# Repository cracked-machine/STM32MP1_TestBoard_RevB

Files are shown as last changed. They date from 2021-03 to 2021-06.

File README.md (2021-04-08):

### STM32MP1 Embedded Linux breakout board RevB

A development board for the STM32MP1 Application Microprocessor with *all MPU pins routed through to 2.54mm headers.* No exotic proprietary connectors needed!

#### Power Supply

The power supply requirements for microprocessors are always complicated. I decided to use a discrete power supply scheme using a single LDO for the main 3.3V rail, a buck regulator for the DDR 1.35V rail and a load switch to detect the USB 1.8V rail. The latter comes from an internal regulator ands powers the VDD3V3_USBFS and VDD3V3_USBHS. This needs to be enabled only after the 1.8V rail comes up, so this needs to be enabled using a MOSFET. However, you need to pick a transistor that will fully switch on for 1.8V Vgs. After having some issues I played it safe with a load switch: the [SIP3250](https://www.mouser.co.uk/datasheet/2/427/sip32508-1763863.pdf), which turns on as low as 1.2V...according to the datasheet

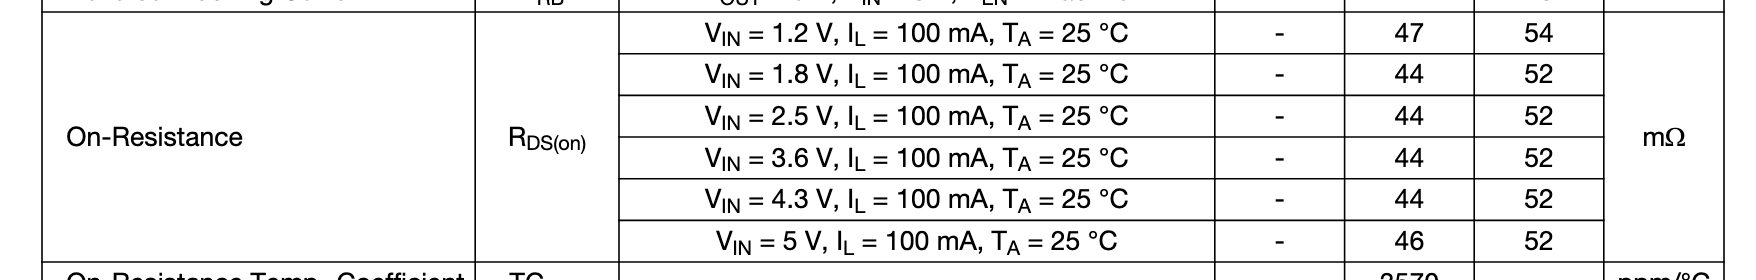
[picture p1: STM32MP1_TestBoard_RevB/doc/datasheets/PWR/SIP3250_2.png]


The characteristics seem to back this up until you get to the Fig.10. Perhaps not quite as good as 1.2Vgs but even at 1.5Vgs, this is more than good enough for these requirements.
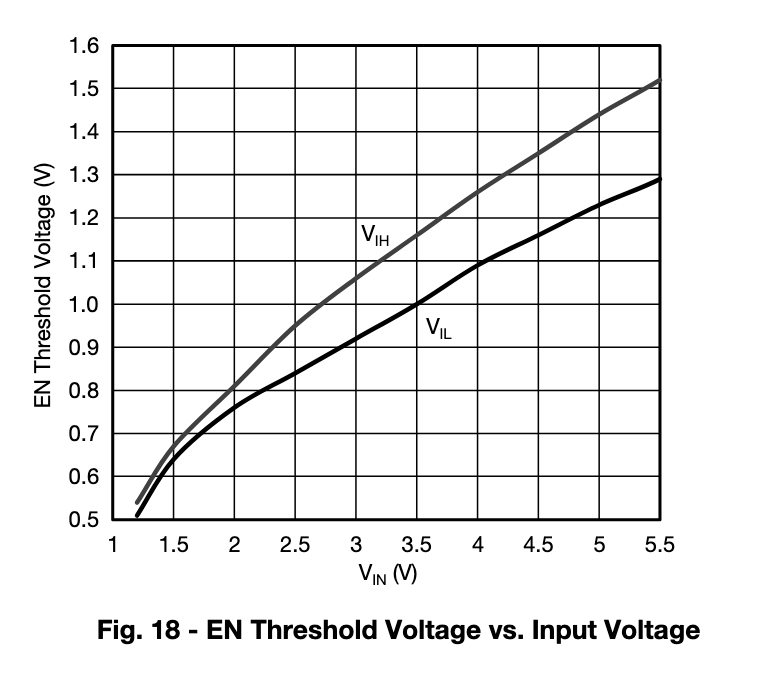
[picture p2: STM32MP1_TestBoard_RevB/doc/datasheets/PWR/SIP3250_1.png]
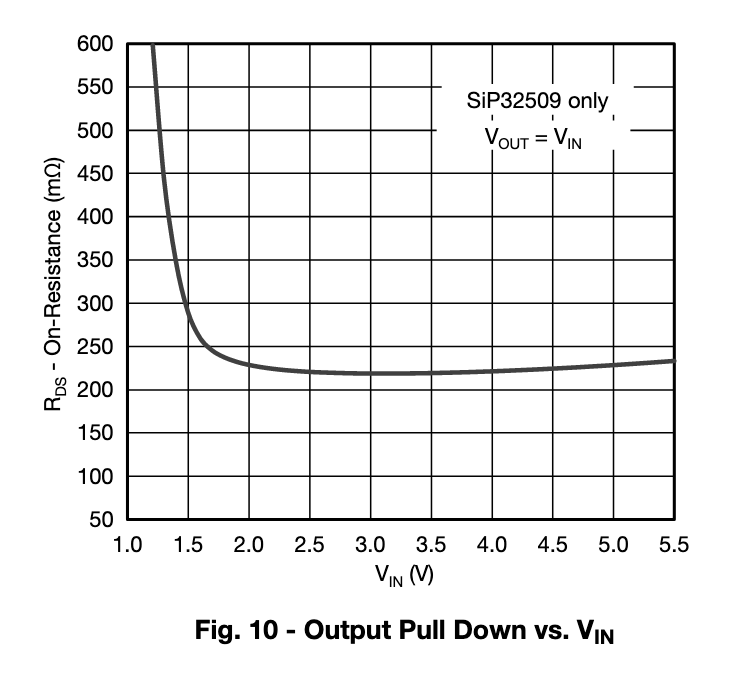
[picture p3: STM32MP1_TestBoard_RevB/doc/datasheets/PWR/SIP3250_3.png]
|||
|:---:|:---:|

Whether this is too much hassle when you can use a single PMIC is debatable. The sheer number of passive components needed to support a PMIC is eye-watering. 

The table below lists the power supply scheme on this board:

|Power Supply Rail|MPU Pin Name|MPU Pin #|Comment|
|:---:|:---|:---|:---:|
|3.3v|VDD<br>VBAT<br>VDD_PLL <br>VDD_PLL2<br>VDD_ANA<br>VDD_DSI<br>PDR_ON_CORE<br>PDR_ON|K6<br>H3<br>J5<br>G13<br>L3<br>A12<br>N1<br>N2|Linear regulator ([SE8233X2](https://datasheet.lcsc.com/szlcsc/1912111437_Seaward-Elec-SE8233X2_C437587.pdf))|
|3.3v|VDDA<br>VREF+|M4<br>N3|via inductor L3<br>If JP4 is connected (default)|
|3.3v|VDD3V3_USBFS<br>VDD3V3_USBHS|W12<br>W15|via NMOS ([DMG2302U](https://datasheet.octopart.com/DMG2302U-7-Diodes-Inc.-datasheet-103571615.pdf)) when 1.85v rail is detected from MPU
|1.35v|VDD<br>VDDQ<br>VDDCORE<br>VDDQ_DDR|B2<br>A1<br>E7<br>E15|Buck regulator [TPS54202](http://www.ti.com/lit/ds/symlink/tps54202.pdf)
|1.85v|VDDA1V8_REG|V11|Internal regulator, externally connect to VDDA1V8_DSI (B12)
|1.2v|VDD1V2_DSI_REG|B16|Internal regulator, externally connected to VDD1V2_DSI_PHY (A16)
|1.1v|VDDA1V1_REG|W11|Interal regulator, internally connected.|

*Note*: 3.3v rail is also connected to:
- SWD debug interface
- SDIO connectors (microSD)
- pull-ups for the BOOT pins
- external power output on the pin headers (pin #26 on J1, J2, J3, J4)

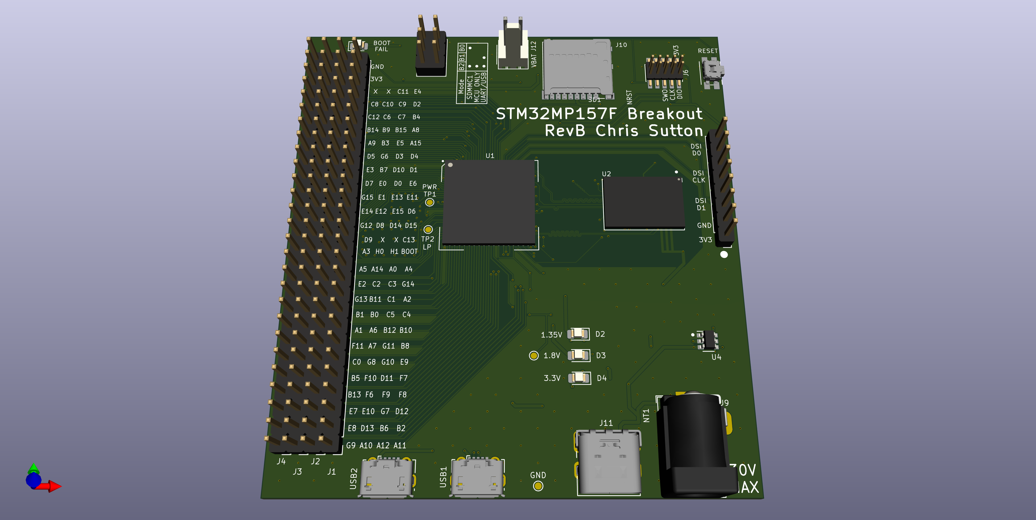
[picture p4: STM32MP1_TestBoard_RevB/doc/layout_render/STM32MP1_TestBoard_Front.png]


[Bill of materials](STM32MP1_TestBoard_RevB/doc/bom/STM32MP1_TestBoard_RevB.csv)

[DataSheets](STM32MP1_TestBoard_RevB/doc/datasheets)

### <U>Schematics:</U>

|Overview|Power Supply|
|:---:|:---:|
||

|STM32MP1 Power|STM32MP1 DDR|
|:---:|:---:|
|||

|STM32MP1 GPIO|STM32MP1 Debug|
|:---:|:---:|
|||

### <U>Testing the bare metal board</U>

Before we boot the board with a Linux image. It is helpful to check the MPU is alive and responding. We can use the SEGGER JLink to connect to the cores via the SWD connector (J6). 

#### Connect to the first A7 core (second core is not active by default):
BOOT pins  must be set to B0 and B2.
```
JLinkExe -device STM32MP15XX_A7_0_DUALFLASH -if SWD -speed 4000 -autoconnect 1
```

```
SEGGER J-Link Commander V6.98a (Compiled Mar  5 2021 17:04:44)
DLL version V6.98a, compiled Mar  5 2021 17:04:29

Connecting to J-Link via USB...O.K.
Firmware: J-Link V11 compiled Feb  4 2021 12:59:17
Hardware version: V11.00
S/N: 261002652
License(s): FlashBP, GDB
OEM: SEGGER-EDU
VTref=3.341V
Device "STM32MP15XX_A7_0_DUALFLASH" selected.

Connecting to target via SWD
ConfigTargetSettings() start
ConfigTargetSettings() end
InitTarget() start
InitTarget() end
Found SW-DP with ID 0x6BA02477
DPIDR: 0x6BA02477
AP map detection skipped. Manually configured AP map found.
AP[0]: AXI-AP (IDR: Not set)
AP[1]: APB-AP (IDR: Not set)
AP[2]: AHB-AP (IDR: Not set)
Using preconfigured AP[1] as APB-AP
AP[1]: APB-AP found
Found Cortex-A7 r0p5
6 code breakpoints, 4 data breakpoints
Debug architecture ARMv7.1
Data endian: little
Main ID register: 0x410FC075
I-Cache L1: 32 KB, 512 Sets, 32 Bytes/Line, 2-Way
D-Cache L1: 32 KB, 128 Sets, 64 Bytes/Line, 4-Way
Unified-Cache L2: 256 KB, 512 Sets, 64 Bytes/Line, 8-Way
System control register:
  Instruction endian: little
  Level-1 instruction cache enabled
  Level-1 data cache enabled
  MMU enabled
  Branch prediction enabled
Memory zones:
  Zone: Default Description: Default access mode
  Zone: APB-AP (AP1) Description: DMA like acc. in AP1 addr. space
  Zone: AHB-AP (AP2) Description: DMA like acc. in AP2 addr. space
Cortex-A7 identified.

```

#### Connect to the M4 core:
BOOT pins  must be set to B2 only.
```
JLinkExe -device STM32MP15XX_M4_DUALFLASH -if SWD -speed 4000 -autoconnect 1
```

```
SEGGER J-Link Commander V6.98a (Compiled Mar  5 2021 17:04:44)
DLL version V6.98a, compiled Mar  5 2021 17:04:29

Connecting to J-Link via USB...O.K.
Firmware: J-Link V11 compiled Feb  4 2021 12:59:17
Hardware version: V11.00
S/N: 261002652
License(s): FlashBP, GDB
OEM: SEGGER-EDU
VTref=3.342V
Device "STM32MP15XX_M4_DUALFLASH" selected.

Connecting to target via SWD
ConfigTargetSettings() start
ConfigTargetSettings() end
InitTarget() start
InitTarget() end
Found SW-DP with ID 0x6BA02477
DPIDR: 0x6BA02477
AP map detection skipped. Manually configured AP map found.
AP[0]: AXI-AP (IDR: Not set)
AP[1]: APB-AP (IDR: Not set)
AP[2]: AHB-AP (IDR: Not set)
AP[2]: Core found
AP[2]: AHB-AP ROM base: 0xE00FF000
CPUID register: 0x410FC241. Implementer code: 0x41 (ARM)
Found Cortex-M4 r0p1, Little endian.
FPUnit: 6 code (BP) slots and 2 literal slots
Detection of Coresight components via ROM table search disabled by user
Cortex-M4 identified.

```

Here is a photo successfully connecting to the A7 core on the assembled board using JLink (via SWD). It lives!

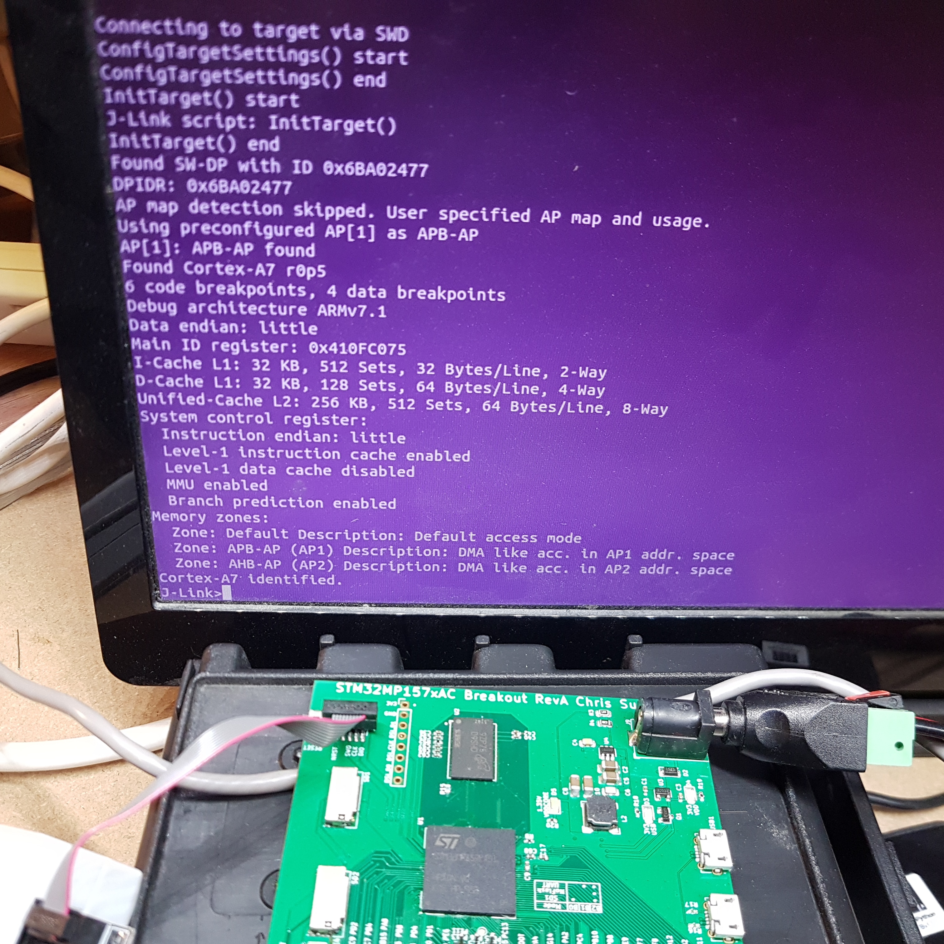
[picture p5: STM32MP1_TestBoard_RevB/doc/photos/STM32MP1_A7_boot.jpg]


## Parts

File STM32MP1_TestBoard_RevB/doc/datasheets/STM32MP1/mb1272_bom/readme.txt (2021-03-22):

******************************************************************************
* @file    readme.txt
* @author  MCD Application Team
* @version 1.0
* @date    17-January-2019 
* @brief   32MP157DISCOVERY BOM files package
******************************************************************************
* COPYRIGHT(c) 2017 STMicroelectronics
*
* The Open Platform License Agreement (“Agreement”) is a binding legal contract
* between you ("You") and STMicroelectronics International N.V. (“ST”), a
* company incorporated under the laws of the Netherlands acting for the purpose
* of this Agreement through its Swiss branch 39, Chemin du Champ des Filles,
* 1228 Plan-les-Ouates, Geneva, Switzerland.
*
* By using the enclosed reference designs, schematics, PC board layouts, and
* documentation, in hardcopy or CAD tool file format (collectively, the
* “Reference Material”), You are agreeing to be bound by the terms and
* conditions of this Agreement. Do not use the Reference Material until You
* have read and agreed to this Agreement terms and conditions. The use of
* the Reference Material automatically implies the acceptance of the Agreement
* terms and conditions.
*
* The complete Open Platform License Agreement can be found on www.st.com/opla.
******************************************************************************

========================
* History
========================

* 1.0 - 17-January-2019
------------------------
    + First official release.

******************* (C) COPYRIGHT 2018 STMicroelectronics *****END OF FILE

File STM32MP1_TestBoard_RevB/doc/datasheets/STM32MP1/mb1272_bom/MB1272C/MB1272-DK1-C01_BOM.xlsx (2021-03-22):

 |  |  | Bill of materials
 |  |  | Board reference: | MB1272
 |  |  | Variant: | DK1
 |  |  | PCB revision: | C
 |  |  | Assembly revision: | 01
 |  |  | Date: | 11/5/2018
Designator | Description | Package | Manufacturer | Manufacturer_Part_Number | Fitted | Quantity
B1, B3, B4 | Switch HW SMD blue |  | JIUBABA | C-TS-02H-2.5-B-V-T/R BLUE | Fitted | 3
B2 | Switch HW SMD black |  | JIUBABA | C-TS-02H-2.5-K-V-T/R BLACK | Fitted | 1
C1, C7, C12, C14, C17, C18, C22, C35, C36, C46, C47, C48, C51, C57, C61, C63, C67, C68, C70, C74, C75, C77, C78, C79, C81, C93, C95, C96, C97, C103, C107, C119, C120, C125, C126, C127, C128, C129, C130, C131, C132, C134, C135, C139, C140, C141, C142, C149, C154, C157, C160, C164, C168, C169, C170, C171, C172, C174, C175, C176, C177, C178, C179, C181, C182, C183, C184, C186, C187, C188 | Capacitor,100nF,16V,X7R,10%,0402, Capacitor,100nF,16V,X7R,10%,0402, Capacitor, MLCC, 100nF, 16V, X7R, 10%, 0402, T=0.5mm, Capacitor,100nF,16V,X7R,10%,0402, Capacitor,100nF,16V,X7R,10%,0402, Capacitor, MLCC, 100nF, 16V, X7R, 10%, 0402, T=0.5mm, Capacitor,100nF,16V,X7R,10%,0402, Capacitor,100nF,16V,X7R,10%,0402, Capacitor,100nF,16V,X7R,10%,0402, Capacitor,100nF,16V,X7R,10%,0402, Capacitor,100nF,16V,X7R,10%,0402, Capacitor,100nF,16V,X7R,10%,0402, Capacitor,100nF,16V,X7R,10%,0402, Capacitor,100nF,16V,X7R,10%,0402, Capacitor,100nF,16V,X7R,10%,0402, Capacitor, MLCC, 100nF, 16V, X7R, 10%, 0402, T=0.5mm, Capacitor, MLCC, 100nF, 16V, X7R, 10%, 0402, T=0.5mm, Capacitor,100nF,16V,X7R,10%,0402, Capacitor,100nF,16V,X7R,10%,0402, Capacitor,100nF,16V,X7R,10%,0402, Capacitor,100nF,16V,X7R,10%,0402, Capacitor,100nF,16V,X7R,10%,0402, Capacitor,100nF,16V,X7R,10%,0402, Capacitor,100nF,16V,X7R,10%,0402, Capacitor,100nF,16V,X7R,10%,0402, Capacitor,100nF,16V,X7R,10%,0402, Capacitor,100nF,16V,X7R,10%,0402, Capacitor,100nF,16V,X7R,10%,0402, Capacitor,100nF,16V,X7R,10%,0402, Capacitor,100nF,16V,X7R,10%,0402, Capacitor,100nF,16V,X7R,10%,0402, Capacitor,100nF,16V,X7R,10%,0402, Capacitor,100nF,16V,X7R,10%,0402, Capacitor,100nF,16V,X7R,10%,0402, Capacitor,100nF,16V,X7R,10%,0402, Capacitor,100nF,16V,X7R,10%,0402, Capacitor,100nF,16V,X7R,10%,0402, Capacitor,100nF,16V,X7R,10%,0402, Capacitor,100nF,16V,X7R,10%,0402, Capacitor,100nF,16V,X7R,10%,0402, Capacitor,100nF,16V,X7R,10%,0402, Capacitor,100nF,16V,X7R,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 | C0402 | YAGEO | CC0402KRX7R7BB104 | Fitted | 70
C10, C16, C20, C23, C26, C31, C32, C33, C49 | Capacitor, MLCC, 4.7uF, 6V3, X5R, 20%, 0402, T=0,5mm | C0402 | MURATA | GRM155R60J475ME47 | Fitted | 9
C100, C101 | Capacitor,150pF,50V,COG,5%,0603 | C0603 | YAGEO | CC0603JRNPO9BN151 | Fitted | 2
C104, C110 | Capacitor,1uF,16V,X5R,10%,0603 | C0603 | YAGEO | CC0603KRX5R7BB105 | Fitted | 2
C106, C113 | Capacitor,22nF,16V,X7R,10%,0402 | C0402 | YAGEO | CC0402KRX7R7BB223 | Fitted | 2
C111 | Capacitor,10uF,6V3,X5R,10%,0603 | C0603 | YAGEO | CC0603KRX5R5BB106 | Fitted | 1
C118, C124, C133, C138 | Capacitor, MLCC, 220uF, 6V3, X5R, 20%, 1206, T=1,6mm | C1206 | MURATA | GRM31CR60J227ME11 | Fitted | 4
C144, C145 | Capacitor,1nF,16V,X7R,10%,0402 | C0402 | YAGEO | CC0402KRX7R7BB102 | Fitted | 2
C15, C27, C39, C62, C64, C65, C72, C73, C89, C94, C102, C105, C108, C109, C112, C143, C146, C147, C148, C150, C152, C153, C155, C156, C158, C159, C161, C162, C163, C165, C191, C192 | Capacitor, MLCC, 1uF, 6V3, X5R, 10%, 0402, T=0,5mm, Capacitor, MLCC, 1uF, 6V3, X5R, 10%, 0402, T=0,5mm, Capacitor, MLCC, 1uF, 6V3, X5R, 10%, 0402, T=0,5mm, Capacitor, MLCC, 1uF, 6V3, X5R, 10%, 0402, T=0,5mm, Capacitor,1uF,6V3,X5R,10%,0402, Capacitor, MLCC, 1uF, 6V3, X5R, 10%, 0402, T=0,5mm, Capacitor,1uF,6V3,X5R,10%,0402, Capacitor,1uF,6V3,X5R,10%,0402, Capacitor,1uF,6V3,X5R,10%,0402, Capacitor,1uF,6V3,X5R,10%,0402, Capacitor,1uF,6V3,X5R,10%,0402, Capacitor,1uF,6V3,X5R,10%,0402, Capacitor,1uF,6V3,X5R,10%,0402, Capacitor,1uF,6V3,X5R,10%,0402, Capacitor,1uF,6V3,X5R,10%,0402, Capacitor,1uF,6V3,X5R,10%,0402, Capacitor,1uF,6V3,X5R,10%,0402, Capacitor,1uF,6V3,X5R,10%,0402, Capacitor,1uF,6V3,X5R,10%,0402, Capacitor,1uF,6V3,X5R,10%,0402, Capacitor,1uF,6V3,X5R,10%,0402, Capacitor,1uF,6V3,X5R,10%,0402, Capacitor,1uF,6V3,X5R,10%,0402, Capacitor,1uF,6V3,X5R,10%,0402, Capacitor,1uF,6V3,X5R,10%,0402, Capacitor,1uF,6V3,X5R,10%,0402, Capacitor,1uF,6V3,X5R,10%,0402, Capacitor,1uF,6V3,X5R,10%,0402, Capacitor,1uF,6V3,X5R,10%,0402, Capacitor,1uF,6V3,X5R,10%,0402, Capacitor,1uF,6V3,X5R,10%,0402, Capacitor,1uF,6V3,X5R,10%,0402 | C0402 | MURATA | GRM155R61E105KA12 | Fitted | 32
C185, C190 | Capacitor,1uF,6V3,X5R,10%,0603 | C0603 | YAGEO | CC0603KRX5R5BB105 | Fitted | 2
C2, C3, C42, C44, C76, C80, C85, C121, C122, C151, C173, C180 | Capacitor, MLCC, 22uF, 6V3, X5R, 20%, 0603, T=0,8mm, Capacitor, MLCC, 22uF, 6V3, X5R, 20%, 0603, T=0,8mm, Capacitor, MLCC, 22uF, 6V3, X5R, 20%, 0603, T=0,8mm, Capacitor, MLCC, 22uF, 6V3, X5R, 20%, 0603, T=0,8mm, Capacitor,22uF,6V3,X5R,20%,0603, Capacitor,22uF,6V3,X5R,20%,0603, Capacitor,22uF,6V3,X5R,20%,0603, Capacitor, MLCC, 22uF, 6V3, X5R, 20%, 0603, T=0,8mm, Capacitor, MLCC, 22uF, 6V3, X5R, 20%, 0603, T=0,8mm, Capacitor,22uF,6V3,X5R,20%,0603, Capacitor,22uF,6V3,X5R,20%,0603, Capacitor,22uF,6V3,X5R,20%,0603 | C0603 | MURATA | GRM188R60J226MEA0J | Fitted | 12
C21, C25, C30, C38, C40, C50, C53, C54, C56, C66, C117, C123, C136, C137 | Capacitor, MLCC, 100nF, 16V, X7R, 10%, 0402, T=0,5mm | C0402 | YAGEO | CC0402KRX7R7BB104 | Fitted | 14
C4, C5, C6, C9, C11, C13, C41, C43 | Capacitor, MLCC, 10uF, 10V, X5R, 10%, 0603, T=0,8mm | C0603 | MURATA | GRM188R61A106KE69D | Fitted | 8
C52 | Polarized Capacitor,10uF,16V,10%,typeA | C1206 | AVX | TAJA106K016R | Fitted | 1
C55 | Capacitor, MLCC, 47uF, 10V, X5R, 20%, 0805, T=1,25mm | C0805 | MURATA | GRM21BR61A476ME15K | Fitted | 1
C58, C59, C87, C88, C90, C91 | Capacitor, MLCC, 6.8pF, 50V, NPO, +-0.25pF, 0402, T=0.5mm | C0402 | YAGEO | CC0402CRNPO9BN6R8 | Fitted | 6
C60 | Capacitor, Tantalum, 47uF, 16V, 10%, TypeC | C2312 | AVX | TAJC476K016RNJ | Fitted | 1
C69, C167 | Capacitor, MLCC, 100pF, 50V, NPO, 5%, 0402, T=0,5mm | C0402 | YAGEO | CC0402JRNPO9BN101 | Fitted | 2
C71, C166 | Capacitor, MLCC, 10uF, 25V, X5R, 10%, 0805, T=0,85mm | C0805 | YAGEO | CC0805KRX5R8BB106 | Fitted | 2
C82, C86, C98, C99 | Capacitor,10pF,50V,NPO,5%,0402 | C0402 | YAGEO | CC0402JRNPO9BN100 | Fitted | 4
C83, C84 | Capacitor, MLCC, 470pF, 50V, NPO, 5%, 0402, T=0,5mm | C0402 | YAGEO | CC0402JRNPO9BN471 | Fitted | 2
C92, C114, C115, C189, C300 | Capacitor, MLCC, 10nF, 16V, X7R, 10%, 0402, T=0.5mm, Capacitor, MLCC, 10nF, 16V, X7R, 10%, 0402, T=0.5mm, Capacitor, MLCC, 10nF, 16V, X7R, 10%, 0402, T=0.5mm, Capacitor,10nF,16V,X7R,10%,0402, Capacitor, MLCC, 10nF, 16V, X7R, 10%, 0402, T=0.5mm | C0402 | YAGEO | CC0402KRX7R7BB103 | Fitted | 5
CN1, CN5 | USB-Receptacle,Dual-Type-A, RA, TH, Height 15.5mm |  | CONEXCON | 5600-3081 | Fitted | 2
CN10 | Connector Jack socket Stereo 3.5mm, 4 pins, RA, SMT, Black |  | LUMBERG | 1503 13 VP3 | Fitted | 1
CN11 | USB-MICRO-B, 0.65mm, RA, SMT, Bottom Mount, |  | MOLEX | 1050170001 | Fitted | 1
CN13 | Socket, 10x1, 2.54mm, VR, SMT, Height 9.78mm |  | SAMTEC | SSW-110-22-L-S-VS | Fitted | 1
CN14, CN16 | Socket, 8x1, 2.54mm, VR, SMT, Height 9.78mm |  | SAMTEC | SSW-108-22-L-S-VS | Fitted | 2
CN15 | MicroSD Card Conn, Reversed-Type, Mnt Push-Push |  | YAMAICHI | PJS008-2003-1 | Fitted | 1
CN17 | Socket, 6x1, 2.54mm, VR, SMT, Height 9.78mm |  | SAMTEC | SSW-106-22-L-S-VS | Fitted | 1
CN2 | Header, 20x2, 2.54mm, VR, TH, Height 5.84mm/2.54mm |  | SAMTEC | TSW-120-07-G-D | Fitted | 1
CN3 | Header 2 circuits, 1.25mm Pitch , Vertical, with Friction Lock |  | MOLEX | 53047-0210 | Fitted | 1
CN4 | Socket ,TEConn,FCC/FPC, 20pins, 1.0mm,SMT, ZIF Receptacle |  | TE CONNECTIVITY | 2-1734248-0 | Fitted | 1
CN6, CN7 | USB tyce C certified receptacle for 1.6mm pcb height |  | CHANT SINCERE (COXOC) | 317JD24BZTF3K3C3 | Fitted | 2
CN8 | Connector RJ45 with Gigabit magnetics and LED , led pull down |  | YUAN DEAN SCIENTIFIC | 48F-01GYDXNL | Fitted | 1
CN9 | HDMI Receptacle Type A 19pins standard Connector |  | FCI | 10029449-001RLF | Fitted | 1
D1, D2 | BAT60JFILM |  | STMICROELECTRONICS | BAT60JFILM | Fitted | 2
F1 | Surface mount resettable polyswitch fuse.I hold=0.35A and I trigger=0.75A | 0805 | TE CONNECTIVITY | picoSMDC035S | Fitted | 1
HW1300 | MICRO_SD_CARD Standard min 4GB |  | NETAC | SD_CARD | Fitted | 1
HW1301 | PCB, xxxx for PCB ref, Y for revision |  | n/a | n/a | Fitted | 1
HW1302 | Sticker to mention board CPN code |  | n/a | n/a | Fitted | 1
HW1303 | Sticker to mention board reference + serial number |  | n/a | n/a | Fitted | 1
L10, L11 | Ferrite bead 100R 2A 0603 |  | MURATA | BLM18EG101TN1 | Fitted | 2
L2, L3, L5, L6 | Power Inductor ,1µH,4.3A max,+-20%,0.042ohm,2520 | 2520 | MURATA | DFE252012P-1ROM=P2 | Fitted | 4
L7 | SMD Chip ferrite bead, 30R@100MHz +/-30%, 5A, 10mohm DC, S (Standard) material, 0603, T=0.8mm |  | TDK | MPZ1608S300A | Fitted | 1
L8 | Bead,26R at 100Mhz,6A,0603 |  | MURATA | BLM18KG260TN1 | Fitted | 1
L9 | IND 4.7µH 20% 80mA 600mhom 0603 | 0603 | MURATA | LQM18FN4R7M00D | Fitted | 1
LD1, LD6 | LED, Red, 0603 | LED 0603 | EVERLIGHT | 19-213-R6C-AP1Q2B/3T | Fitted | 2
LD2, LD3, LD5, LD9 | LED, Green, 0603 | LED 0603 | EVERLIGHT | 19-213SYGC/S530-E2/TR8 | Fitted | 4
LD4 | LED Bicolor |  | AVAGO TECHNOLOGIES | HSMF-A201-A00J1 | Fitted | 1
LD7 | LED, Orange, 0603 | LED 0603 | EVERLIGHT | 19-217/S2C-AM2N2VY/3T | Fitted | 1
LD8 | LED Blue, 0603 SMD, Forward Voltage Min=2,8V, Max=3,1V | 0603 | EVERLIGHT | 19-217-BHC-ZL1M2RY-3T | Fitted | 1
LE1 | FIXED IND 4.7UH 1A 180 MOHM 30% SMD |  | MURATA | LQH32PN4R7NN0L | Fitted | 1
Q1 | Transistor 45V Matched Pair PNP small Signal transistor in SOT363 | SOT363 | DIODES_INC | BCM857BS7F | Fitted | 1
Q2, T1, T2 | Power Mosfet, P-channel,VDS -30V,RDS 12mohm typ,ID -9A | PowerFLAT 3.3x3.3 | STMICROELECTRONICS | STL9P3LLH6 | Fitted | 3
R1, R2, R5, R7, R65, R75, R76, R93, R166, R167 | Resistor,1K5,0402,1%,1/16W | R0402 | YAGEO | RC0402FR-071K5L | Fitted | 10
R107, R108 | Resistor,680R,0402,1%,1/16W | R0402 | YAGEO | RC0402FR-07680RL | Fitted | 2
R11, R18, R19, R37, R40, R42, R80, R81, R84, R87, R96, R99, R109, R136, R164, R300, R302, R600 | Resistor,10K,0402,1%,1/16W | R0402 | YAGEO | RC0402FR-0710KL | Fitted | 18
R112 | Resistor,36K,0402,1%,1/16W | R0402 | YAGEO | RC0402FR-0736KL | Fitted | 1
R115, R116, R117, R118, R121, R122, R123, R124, R126, R128, R130, R131, R132, R133, R135, R138, R141, R142, R143, R144, R145, R146, R147, R148 | Resistor,56R,0402,1%,1/16W | R0402 | YAGEO | RC0402FR-0756RL | Fitted | 24
R14, R16, R25, R28, R33, R39, R45, R49, R56, R120 | Resistor,47K,0402,1%,1/16W | R0402 | YAGEO | RC0402FR-0747KL | Fitted | 10
R15, R38 | Resistor,240R,0402,1%,1/16W | R0402 | YAGEO | RC0402FR-07240RL | Fitted | 2
R155 | Resistor,2K49,0402,1%,1/16W | R0402 | YAGEO | RC0402FR-072K49L | Fitted | 1
R21, R43, R82, R101, R102, R106, R303 | Resistor,1K,0402,1%,1/16W | R0402 | YAGEO | RC0402FR-071KL | Fitted | 7
R23, R100, R119, R127, R129, R134, R137, R139, R140, R159, R161 | Resistor,100K,0402,1%,1/16W | R0402 | YAGEO | RC0402FR-07100KL | Fitted | 11
R24 | Resistor,12K,0402,1%,1/16W | R0402 | YAGEO | RC0402FR-0712KL | Fitted | 1
R3, R47, R150 | Resistor,0R,0603,ULO | R0603 | ROHM | PMR03EZPJ000 | Fitted | 3
R304 | Resistor,10R,0402,1%,1/16W | R0402 | YAGEO | RC0402FR-0710RL | Fitted | 1
R4, R6, R8, R10, R13, R31, R34, R35, R36, R46, R58, R59, R64, R68, R71, R72, R73, R77, R79, R85, R86, R152, R154, R158, R165 | Resistor,0R,0402,5%,1/16W | R0402 | YAGEO | RC0402JR-070RL | Fitted | 25
R41, R89, R90, R105 | Resistor,330R,0402,1%,1/16W | R0402 | YAGEO | RC0402FR-07330RL | Fitted | 4
R44 | Resistor,3K,0402,1%,1/16W | R0402 | YAGEO | RC0402FR-073KL | Fitted | 1
R48, R57, R70 | Resistor,5K1,0402,1%,1/16W | R0402 | YAGEO | RC0402FR-075K1L | Fitted | 3
R50, R51, R52, R53, R54, R55, R67, R91, R94, R149, R156, R163 | Resistor,4K7,0402,1%,1/16W | R0402 | YAGEO | RC0402FR-074K7L | Fitted | 12
R60, R61, R62, R63, R153 | Resistor,22R,0402,1%,1/16W | R0402 | YAGEO | RC0402FR-0722RL | Fitted | 5
R66, R114, R157, R162 | Resistor,510R,0402,1%,1/16W | R0402 | YAGEO | RC0402FR-07510RL | Fitted | 4
R83, R151, R160 | Resistor,0R,0603,5%,1/10W | R0603 | YAGEO | RC0603JR-070RL | Fitted | 3
R88, R104, R110, R111, R125 | Resistor,100R,0402,1%,1/16W | R0402 | YAGEO | RC0402FR-07100RL | Fitted | 5
R92, R103 | Resistor,51R,0402,1%,1/16W | R0402 | YAGEO | RC0402FR-0751RL | Fitted | 2
R95, R97, R98 | Resistor,2K2,0402,1%,1/16W | R0402 | YAGEO | RC0402FR-072K2L | Fitted | 3
SB1, SB2, SB3, SB4, SB5, SB6, SB9, SB10, SB17, SB19, SB20, SB21, SB22, SB24, SB26 | Solder Bridge ON | SB0603 | YAGEO | RC0603JR-070RL | Fitted | 15
SW1 | Dip Switch ,2Position ,Surface Mount Slide (Standard) ,2.54 pitch,25mA 24VDC | DIP | C&K | SDA02H1SBD | Fitted | 1
T3, T4 | NPN Bipolar Transistor |  | ON SEMICONDUCTOR | BSR14 | Fitted | 2
TP10, TP13, TP14 | Test Point 0.6mm |  |  |  | Fitted | 3
U1, U2, U6, U9, U29 | Common mode filter with ESD protection for USB 2.0 interface |  | STMICROELECTRONICS | ECMF02-2AMX6 | Fitted | 5
U10, U26 | 4-line ESD protection for high speed lines | uQFN-10L | STMICROELECTRONICS | HSP051-4M10 | Fitted | 2
U12 | USB Type-C controller with VCONN switch |  | STMICROELECTRONICS | STUSB1600AQTR | Fitted | 1
U13 | MPU TFBGA12x12 without crypto | TFBGA12x12 | STMICROELECTRONICS | STM32MP157AAC3 | Fitted | 1
U14 | HDMI Transmitter, 72-pin 10 × 10 mm QFN |  | LATTICE | SiI9022ACNU | Fitted | 1
U15, U17 | DUAL TRANSIL ARRAY FOR ESD PROTECTION | ESD_SOT23 | STMICROELECTRONICS | ESDA25L | Fitted | 2
U16, U23, U24, U25, U27, U28, U30 | High power transient voltage suppressor | QFN1610 | STMICROELECTRONICS | ESDA7P120-1U1M | Fitted | 7
U18 | 10/100/1000M GIGABIT Ethernet Transceiver, QFN40 , SMPS version |  | REALTEK | RTL8211F-CG | Fitted | 1
U19 | Medium-density performance line ARM-based 32-bit MCU with 128KB Flash |  | STMICROELECTRONICS | STM32F103CBT6 | Fitted | 1
U20 | Low-Power, Stereo Codec with Headphone Amp |  | CIRRUS LOGIC | CS42L51-CNZ | Fitted | 1
U21 | USB OTG FS ESD protection |  | STMICROELECTRONICS | USBLC6-2P6 | Fitted | 1
U22 | Quad Bidir ESD protection |  | STMICROELECTRONICS | ESDA6V1BC6 | Fitted | 1
U3, U11 | IC,Dual-Channel-Power-Switch,500mA,100mR,SO8 |  | STMICROELECTRONICS | STMPS2252MTR | Fitted | 2
U31, U32 | ESD protection & Common Filter High Speed serial Interfaces |  | STMICROELECTRONICS | ECMF04-4HSWM10 | Fitted | 2
U33 | ESD protection , 5 lines | QFN | STMICROELECTRONICS | ESDALC6V1-5M6 | Fitted | 1
U34 | Ultra low drop-low noise BiCMOS voltage, regulators low ESR capacitors compatible |  | STMICROELECTRONICS | LD3985M33R | Fitted | 1
U35 | ESD protection 6V1 |  | STMICROELECTRONICS | ESDALC6V1-1U2 | Fitted | 1
U4 | ST PMIC: 4 step-down + 1 advanced boost SMPS, 6 LDOs, 2 pwr switches, DDR Vref, NVM option 'A' for IO@3.3V | WFQFN 5.0x6.0x0.80mm | STMICROELECTRONICS | STPMIC1APQR | Fitted | 1
U5 | Memory,DDR3L,4Gb,256Mbx16,1866MT/s,1V35,FBGA96 |  | MICRON | MT41K256M16TW-107-P-V00H | Fitted | 1
U7 | USB HUB 2,0 Controller |  | MICROCHIP | USB2514B-AEZC | Fitted | 1
X1 | Crystal 24MHz, 6pF, +-20ppm, 80ohms max, SMD | (2016) 2.0 x 1.6 x 0.45 mm | NDK | NX2016SA 24MHz EXS00A-CS10820 | Fitted | 1
X2 | Crystal 25Mhz, 10pF, -+50PPM, SMD | 3225 | NDK | NX3225GA 25MHz EXS00A-CG06750 | Fitted | 1
X4 | Crystal 32.768kHz, 6pF, -+20PPM, R=80K, SMD | NX2012SA | NDK | NX2012SA 32.768KHz EXS00A-MU00527 | Fitted | 1
X5 | Crystal 8Mhz, 8pF, -+50PPM, SMD |  | NDK | NX3225GD 8MHz EXS00A-CG04874 | Fitted | 1
X6 | Oscillator 24Mhz, +-50ppm, Vcc:3.3V typ (1.62V min), square wave: [0.1Vcc;0.9Vcc], Enable pin | 2.0x1.6x0.7mm | NDK | NZ2016SH 24MHz END4869F | Fitted | 1
C28 | Capacitor, MLCC, 2.2uF, 10V, X5R, 10%, 0603, T=0,8mm | C0603 | YAGEO | CC0603KRX5R6BB225 | Not Fitted | 0
C29 | Capacitor, MLCC, 10uF, 10V, X5R, 10%, 0603, T=0,8mm | C0603 | MURATA | GRM188R61A106KE69D | Not Fitted | 0
C37 | Capacitor, MLCC, 4.7uF, 6V3, X5R, 20%, 0402, T=0,5mm | C0402 | MURATA | GRM155R60J475ME47 | Not Fitted | 0
C45 | Capacitor,100nF,16V,X7R,10%,0402 | C0402 | YAGEO | CC0402KRX7R7BB104 | Not Fitted | 0
C8, C19, C24, C34 | Capacitor, MLCC, 12pF, 50V, NPO, 5%, 0402, T=0,5mm | C0402 | YAGEO | CC0402JRNPO9BN120 | Not Fitted | 0
CN12 | Header, 4x1, 2,54mm, VR, TH, Height 5.84mm/2.54mm |  | SAMTEC | TSW-104-07-x-S | Not Fitted | 0
L1 | Inductor,2.4nH,+-0.2nH,0.05R,0.85A,0402 | L0402 | MURATA | LQW15AN2N4C00x | Not Fitted | 0
L4 | Inductor, 2.2µH, 20%, Isat 0.35A, DCR 0.2Ohm, 0603 | L0603 | MURATA | LQM18PN2R2MGH | Not Fitted | 0
R12, R17, R20, R22, R26, R27 | Resistor,47K,0402,1%,1/16W | R0402 | YAGEO | RC0402FR-0747KL | Not Fitted | 0
R69 | Resistor,22R,0402,1%,1/16W | R0402 | YAGEO | RC0402FR-0722RL | Not Fitted | 0
R9, R32, R74, R78 | Resistor,0R,0402,5%,1/16W | R0402 | YAGEO | RC0402JR-070RL | Not Fitted | 0
SB23, SB25 | Solder Bridge ON | SB0603 | YAGEO | RC0603JR-070RL | Not Fitted | 0
SB7, SB8, SB11, SB12, SB13, SB14, SB15, SB16, SB18 | Solder Bridge OFF | SB0603 | YAGEO | RC0603JR-070RL | Not Fitted | 0
U8 | IEEE802.11b/g/n W-LAN + Bluetooth 4.1+EDR module |  | MURATA | LBEE5KL1DX-883 | Not Fitted | 0

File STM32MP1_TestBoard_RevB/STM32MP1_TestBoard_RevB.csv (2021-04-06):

Reference | Quantity | Value | Footprint | Datasheet | Comment | LCSC | Mfr | Mouser | PartNo
C1 | 1 | 1uF | Capacitor_SMD:C_0805_2012Metric_Pad1.18x1.45mm_HandSolder | ~ | ~ | C28323 | ~ | ~ | ~
C11 C16 | 2 | 6.8pF NP0 | Capacitor_SMD:C_0402_1005Metric_Pad0.74x0.62mm_HandSolder | ~ | ~ | C1576 | ~ | ~ | ~
C13 C15 C37 | 3 | 10nF | Capacitor_SMD:C_0402_1005Metric_Pad0.74x0.62mm_HandSolder | ~ | ~ | C15195 | ~ | ~ | ~
C12 C14 C17 C18 C19 C20 C21 C22 C23 C24 C25 C26 C27 C28 C29 C30 C31 C32 C33 C34 C35 C68 C70 | 23 | 1uF | Capacitor_SMD:C_0402_1005Metric_Pad0.74x0.62mm_HandSolder | https://datasheet.lcsc.com/szlcsc/1810201223_Taiyo-Yuden-LMK105BJ105KV-F_C87145.pdf | ~ | C52923 | Taiyo Yuden | ~ | LMK105BJ105KV-F
C2 C5 C8 C10 | 4 | 22uF | Capacitor_SMD:C_1206_3216Metric_Pad1.33x1.80mm_HandSolder | https://www.mouser.co.uk/datasheet/2/212/KEM_C1006_X5R_SMD-1103249.pdf | ~ | ~ | Kemet | ~ | C1206C226M8PACTU
C3 | 1 | 10uF | Capacitor_SMD:C_0805_2012Metric_Pad1.18x1.45mm_HandSolder | ~ | ~ | ~ | ~ | ~ | ~
C36 C38 C40 C41 C42 C44 C52 C57 C62 C65 | 10 | 100nF | Capacitor_SMD:C_0402_1005Metric_Pad0.74x0.62mm_HandSolder | ~ | ~ | C1525 | ~ | ~ | ~
C39 C43 | 2 | 2.2uF | Capacitor_SMD:C_0805_2012Metric_Pad1.18x1.45mm_HandSolder | ~ |  | C49217 | ~ | ~ | ~
C4 | 1 | 100nF | Capacitor_SMD:C_0805_2012Metric_Pad1.18x1.45mm_HandSolder | ~ | ~ | C49678 | ~ | ~ | ~
C6 | 1 | 56pF | Capacitor_SMD:C_0805_2012Metric_Pad1.18x1.45mm_HandSolder | ~ | ~ | C1828 | ~ | ~ | ~
C7 C9 C69 | 3 | 2.2uF | Capacitor_SMD:C_0402_1005Metric_Pad0.74x0.62mm_HandSolder | https://datasheet.lcsc.com/szlcsc/1810201223_Taiyo-Yuden-LMK105BJ105KV-F_C87145.pdf | ~ | ~ | Taiyo Yuden | ~ | LMK105BJ105KV-F
D1 D2 D3 D4 | 4 | LED | LED_SMD:LED_0805_2012Metric_Pad1.15x1.40mm_HandSolder | ~ | ~ | C84256 | ~ | ~ | ~
J1 J2 J3 J4 | 4 | Conn_01x27 | Connector_PinHeader_2.54mm:PinHeader_1x27_P2.54mm_Vertical | ~ | ~ | ~ | ~ | ~ | ~
J10 | 1 | Micro_SD_Card_Det | Connector_Card:microSD_HC_Molex_104031-0811 | https://www.molex.com/webdocs/datasheets/pdf/en-us/1040310811_MEMORY_CARD_SOCKET.pdf | ~ | ~ | Molex | 538-104031-0811 | 104031-0811
J11 | 1 | USB_C_Receptacle_USB2.0 | MolexUSB_TypeC:213716-0001_THT_Socket_RightAngle | https://www.molex.com/webdocs/datasheets/pdf/en-us/2137160001_IO_CONNECTORS.pdf | ~ | ~ | Molex | 538-213716-0001 | 213716-0001
J12 | 1 | Conn_01x02 | Connector_Molex:Molex_KK-254_AE-6410-02A_1x02_P2.54mm_Vertical | ~ | ~ | ~ | ~ | ~ | ~
J8 J14 | 2 | USB_B_Micro | Connector_USB:USB_Micro-B_Molex-105017-0001 | ~ | ~ | ~ | ~ | ~ | ~
J5 | 1 | Conn_02x03_Odd_Even | Connector_PinHeader_2.54mm:PinHeader_2x03_P2.54mm_Vertical | ~ | ~ | ~ | ~ | ~ | ~
J6 | 1 | Conn_02x05_Odd_Even | Connector_PinHeader_1.27mm:PinHeader_2x05_P1.27mm_Vertical_SMD | https://docs.rs-online.com/75e3/0900766b8142184e.pdf | ~ | ~ | Amphenol ICC | ~ | 20021121-00010C4LF
J7 | 1 | Conn_01x08 | Connector_PinHeader_2.54mm:PinHeader_1x08_P2.54mm_Vertical | ~ | ~ | ~ | ~ | ~ | ~
J9 | 1 | Barrel_Jack | Connector_BarrelJack:BarrelJack_Horizontal | ~ | ~ | ~ | ~ | ~ | ~
L2 | 1 | 4.7uH | Inductor_SMD:L_Bourns-SRN6028 | https://datasheet.lcsc.com/szlcsc/1808311234_SXN-Shun-Xiang-Nuo-Elec-SMNR6028-4R7MT_C266428.pdf | ~ | ~ | Shun Xiang Nuo Elec | ~ | SMNR6028-4R7MT
L3 | 1 | LQM18FN4R7M00D | Inductor_SMD:L_0201_0603Metric_Pad0.64x0.40mm_HandSolder | https://www.mouser.co.uk/datasheet/2/281/JELF243B-0012-1633801.pdf | ~ | ~ | ~ | 81-LQM18FN4R7M00D | ~
NT1 | 1 | Net-Tie_3 | NetTie:NetTie-3_SMD_Pad0.5mm | ~ | ~ | ~ | ~ | ~ | ~
NT2 NT3 | 2 | Net-Tie_2 | TinyNetTies:NetTie-2_SMD_Pad0.127mm | ~ | ~ | ~ | ~ | ~ | ~
R10 R11 | 2 | 240R | Resistor_SMD:R_0402_1005Metric_Pad0.72x0.64mm_HandSolder | ~ | ~ | ~ | ~ | ~ | ~
R12 R13 R40 R41 R42 | 5 | 47K | Resistor_SMD:R_0402_1005Metric_Pad0.72x0.64mm_HandSolder | ~ | ~ | C25792 | ~ | ~ | ~
R14 | 1 | 100R | Resistor_SMD:R_0402_1005Metric_Pad0.72x0.64mm_HandSolder | ~ | ~ | C25076 | ~ | ~ | ~
R18 R19 R26 | 3 | 2K2 | Resistor_SMD:R_0402_1005Metric_Pad0.72x0.64mm_HandSolder | ~ | ~ | C25879 | ~ | ~ | ~
R1 R2 R5 R7 R9 R22 R52 | 7 | 1K | Resistor_SMD:R_0402_1005Metric_Pad0.72x0.64mm_HandSolder | ~ | ~ | C11702 | ~ | ~ | ~
R20 | 1 | 10R | Resistor_SMD:R_0402_1005Metric_Pad0.72x0.64mm_HandSolder | ~ | ~ | C25077 | ~ | ~ | ~
R16 R17 R23 R24 | 4 | 0R | Resistor_SMD:R_0402_1005Metric_Pad0.72x0.64mm_HandSolder | ~ | ~ | C25087 |  | ~
R25 | 1 | 0R | Capacitor_SMD:C_0402_1005Metric_Pad0.74x0.62mm_HandSolder | ~ | ~ | C25087 | ~ | ~ | ~
R3 | 1 | 100K | Resistor_SMD:R_0805_2012Metric_Pad1.20x1.40mm_HandSolder | ~ | ~ | C17407 | ~ | ~ | ~
R4 | 1 | 82K | Resistor_SMD:R_0805_2012Metric_Pad1.20x1.40mm_HandSolder | ~ | ~ | C17840 | ~ | ~ | ~
R6 R15 R21 | 3 | 10K | Resistor_SMD:R_0402_1005Metric_Pad0.72x0.64mm_HandSolder | ~ | ~ | C25744 | ~ | ~ | ~
R8 | 1 | 3K | Resistor_SMD:R_0402_1005Metric_Pad0.72x0.64mm_HandSolder | ~ | ~ | ~ | ~ | ~ | ~
SW2 | 1 | SW_SPST | Button_Switch_SMD:Panasonic_EVQPUK_EVQPUB | https://industrial.panasonic.com/cdbs/www-data/pdf/ATK0000/ATK0000C382.pdf | ~ | ~ | ~ | ~ | ~
TP1 TP2 | 2 | TestPoint | TestPoint:TestPoint_Pad_D1.0mm | ~ | ~ | ~ | ~ | ~ | ~
U1 | 1 | STM32MP157xAB | STM32MP151_LFBGA:BGA-354_19x19_16.0x16.0mm | https://www.st.com/resource/en/datasheet/stm32mp151c.pdf | ~ | ~ | ~ | ~ | ~
U2 | 1 | MT41K256M16TW-107 | Package_BGA:BGA-96_9.0x13.0mm_Layout2x3x16_P0.8mm | https://www.mouser.co.uk/datasheet/2/671/4Gb_DDR3L-1283964.pdf | ~ | ~ | Micron | ~ | MT41K256M16TW-107
U3 | 1 | SE8233X2 | Package_TO_SOT_SMD:SOT-23 | https://datasheet.lcsc.com/szlcsc/1912111437_Seaward-Elec-SE8233X2_C437587.pdf | ~ | ~ | ~ | ~ | ~
U4 | 1 | TPS54202DDC | Package_TO_SOT_SMD:SOT-23-6 | http://www.ti.com/lit/ds/symlink/tps54202.pdf | ~ | ~ | Texas Instruments | ~ | TPS54202DDCR
U5 U6 | 2 | SiP3250x | Package_TO_SOT_SMD:SOT-23-6_Handsoldering | https://www.mouser.co.uk/datasheet/2/427/sip32508-1763863.pdf | ~ | ~ | ~ | 78-SIP32508DT-T1-GE3 | SIP32508DT-T1-GE3
X1 | 1 | NX2016SA-24M | Oscillator:Oscillator_SMD_Abracon_ASE-4Pin_3.2x2.5mm | http://www.abracon.com/Oscillators/ASV.pdf | 24MHz, 6pF, +-20ppm, 80ohms max, SMD | ~ | NDK | 344-NX2016SA24S08891 | NX2016SA-24M-EXS00A-CS08891
Y1 | 1 | NX2012SA32768K1 | Crystal:Crystal_SMD_2012-2Pin_2.0x1.2mm_HandSoldering | https://www.mouser.co.uk/datasheet/2/122/ECX-12R-1314062.pdf | 32.768KHz NP0 +/-0.25pF 50V | ~ | ECS | 520-.327-12.5-12R-T | ECS-.327-12.5-12R-TR

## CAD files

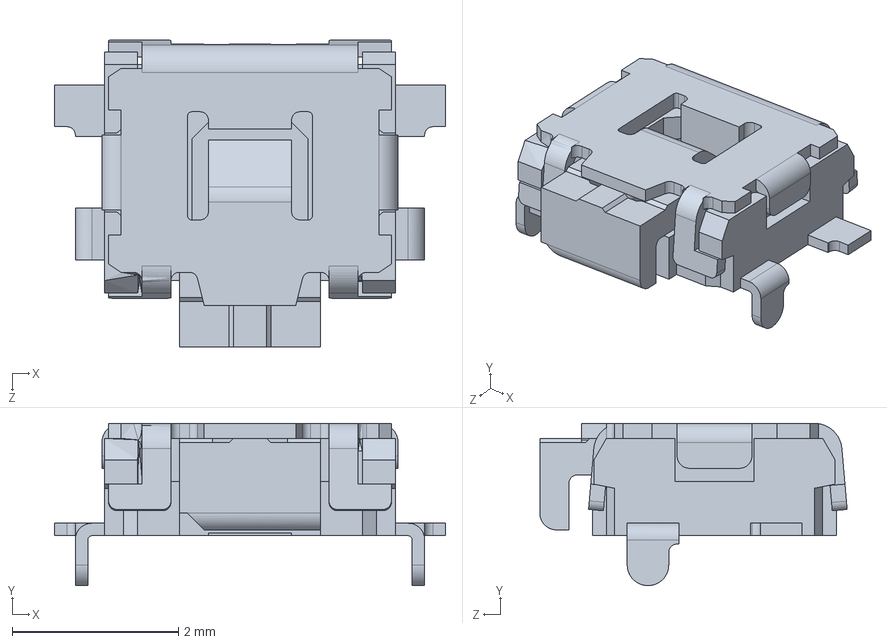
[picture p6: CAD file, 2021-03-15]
STM32MP1_TestBoard_RevB/doc/3d/EVQ-9P7_P34-01P.STEP
4.70 x 1.95 x 3.69 mm

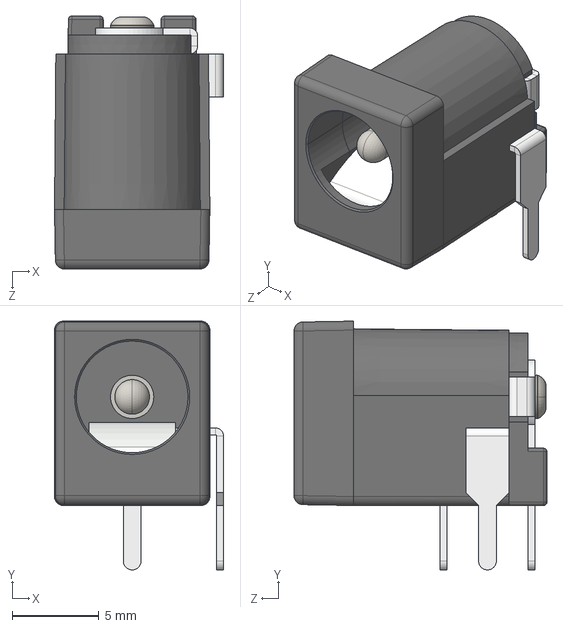
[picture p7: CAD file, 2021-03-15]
STM32MP1_TestBoard_RevB/doc/3d/DC Power Jack 5.5mm x 2.1mm.STEP
9.77 x 14.4 x 14.6 mm

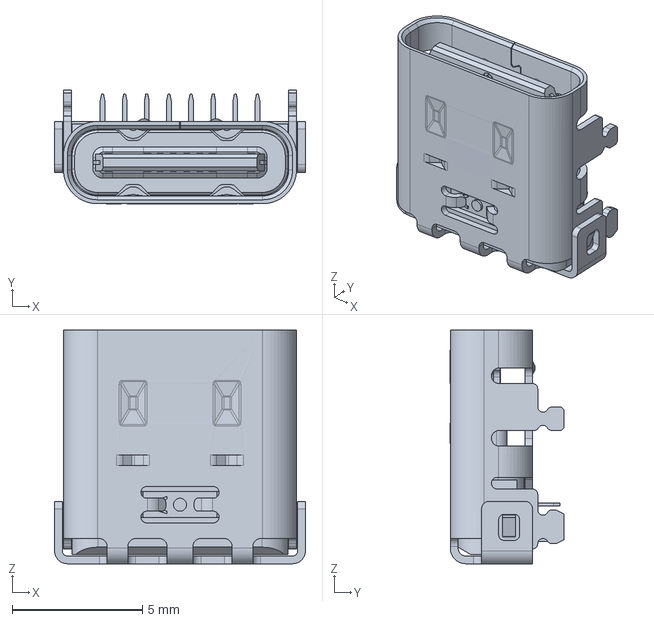
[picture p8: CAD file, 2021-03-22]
STM32MP1_TestBoard_RevB/doc/3d/2137160001.stp
9.64 x 4.36 x 8.97 mm

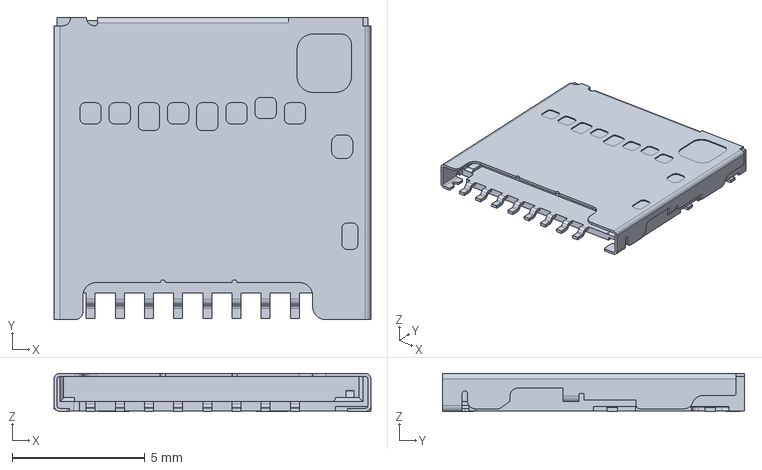
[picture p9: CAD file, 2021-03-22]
STM32MP1_TestBoard_RevB/doc/3d/1040310811.stp
11.9 x 11.4 x 1.45 mm

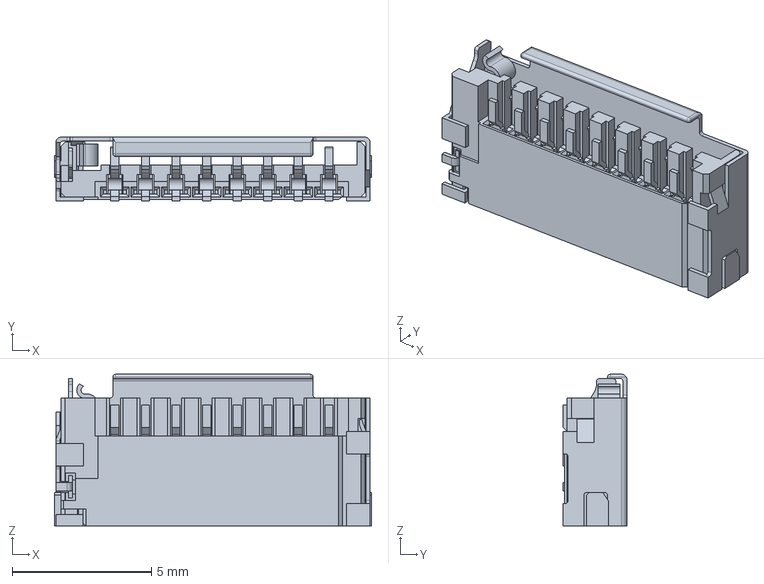
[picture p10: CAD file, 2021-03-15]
STM32MP1_TestBoard_RevB/doc/3d/475710001.stp
11.4 x 2.30 x 5.45 mm

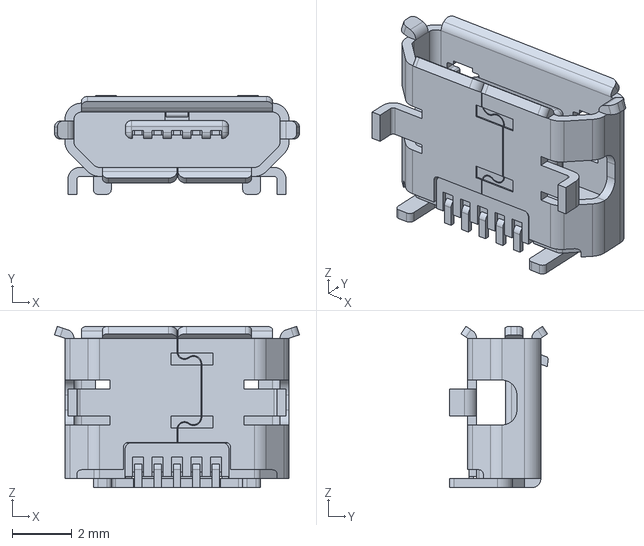
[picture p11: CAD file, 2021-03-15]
STM32MP1_TestBoard_RevB/doc/3d/1050170001.stp
8.20 x 3.30 x 5.40 mm

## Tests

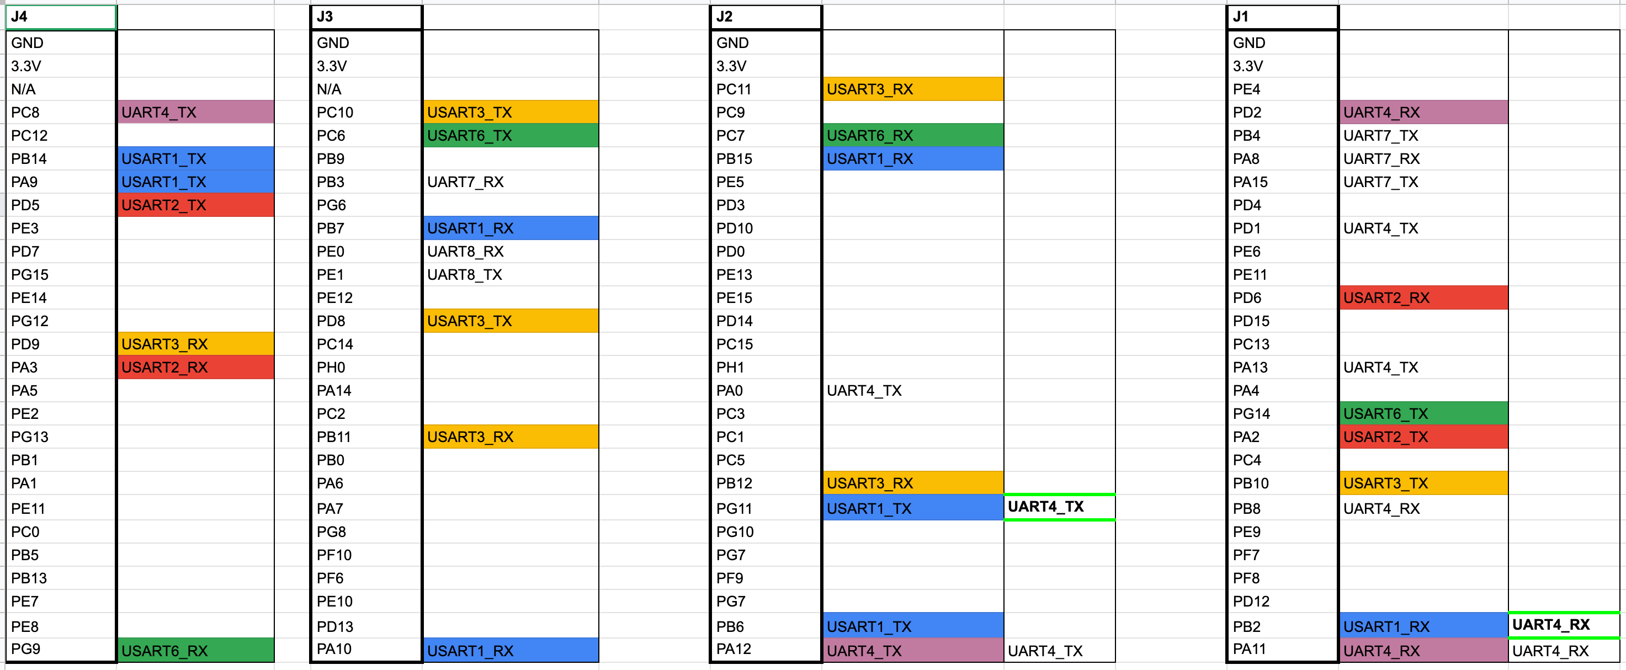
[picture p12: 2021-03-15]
STM32MP1_TestBoard_RevB/doc/UART_Pin_Map/STM32MP157xAC_LFBGA35_BreakoutBoard_Pin_List.png

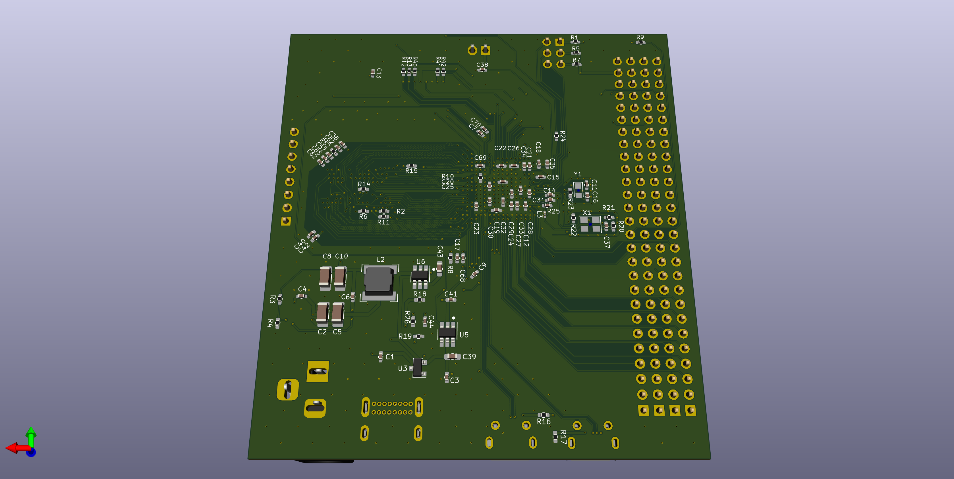
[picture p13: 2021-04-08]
STM32MP1_TestBoard_RevB/doc/layout_render/STM32MP1_TestBoard_Back.png

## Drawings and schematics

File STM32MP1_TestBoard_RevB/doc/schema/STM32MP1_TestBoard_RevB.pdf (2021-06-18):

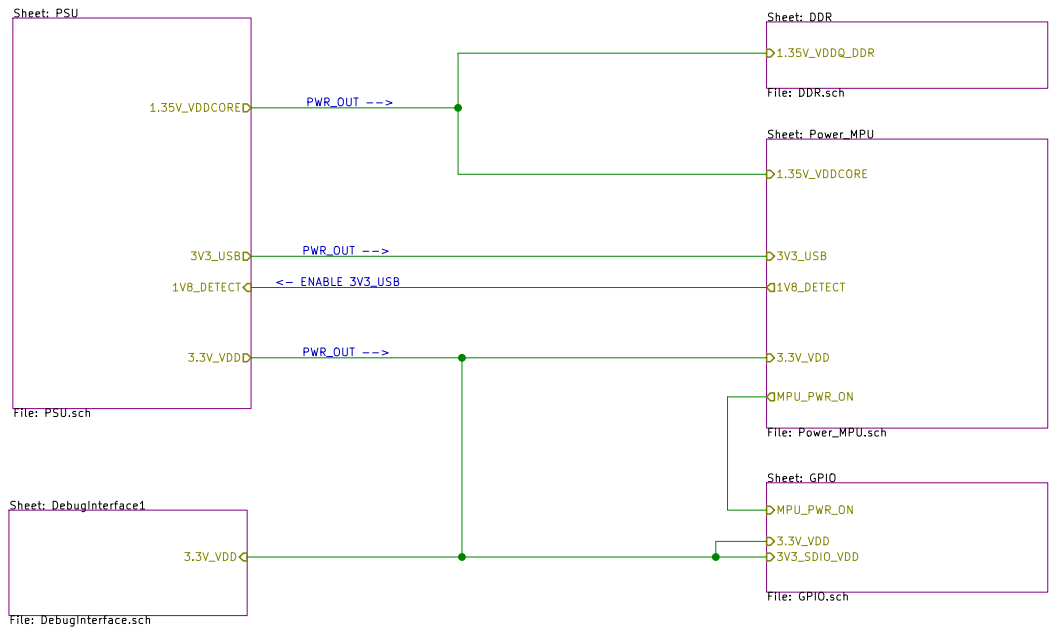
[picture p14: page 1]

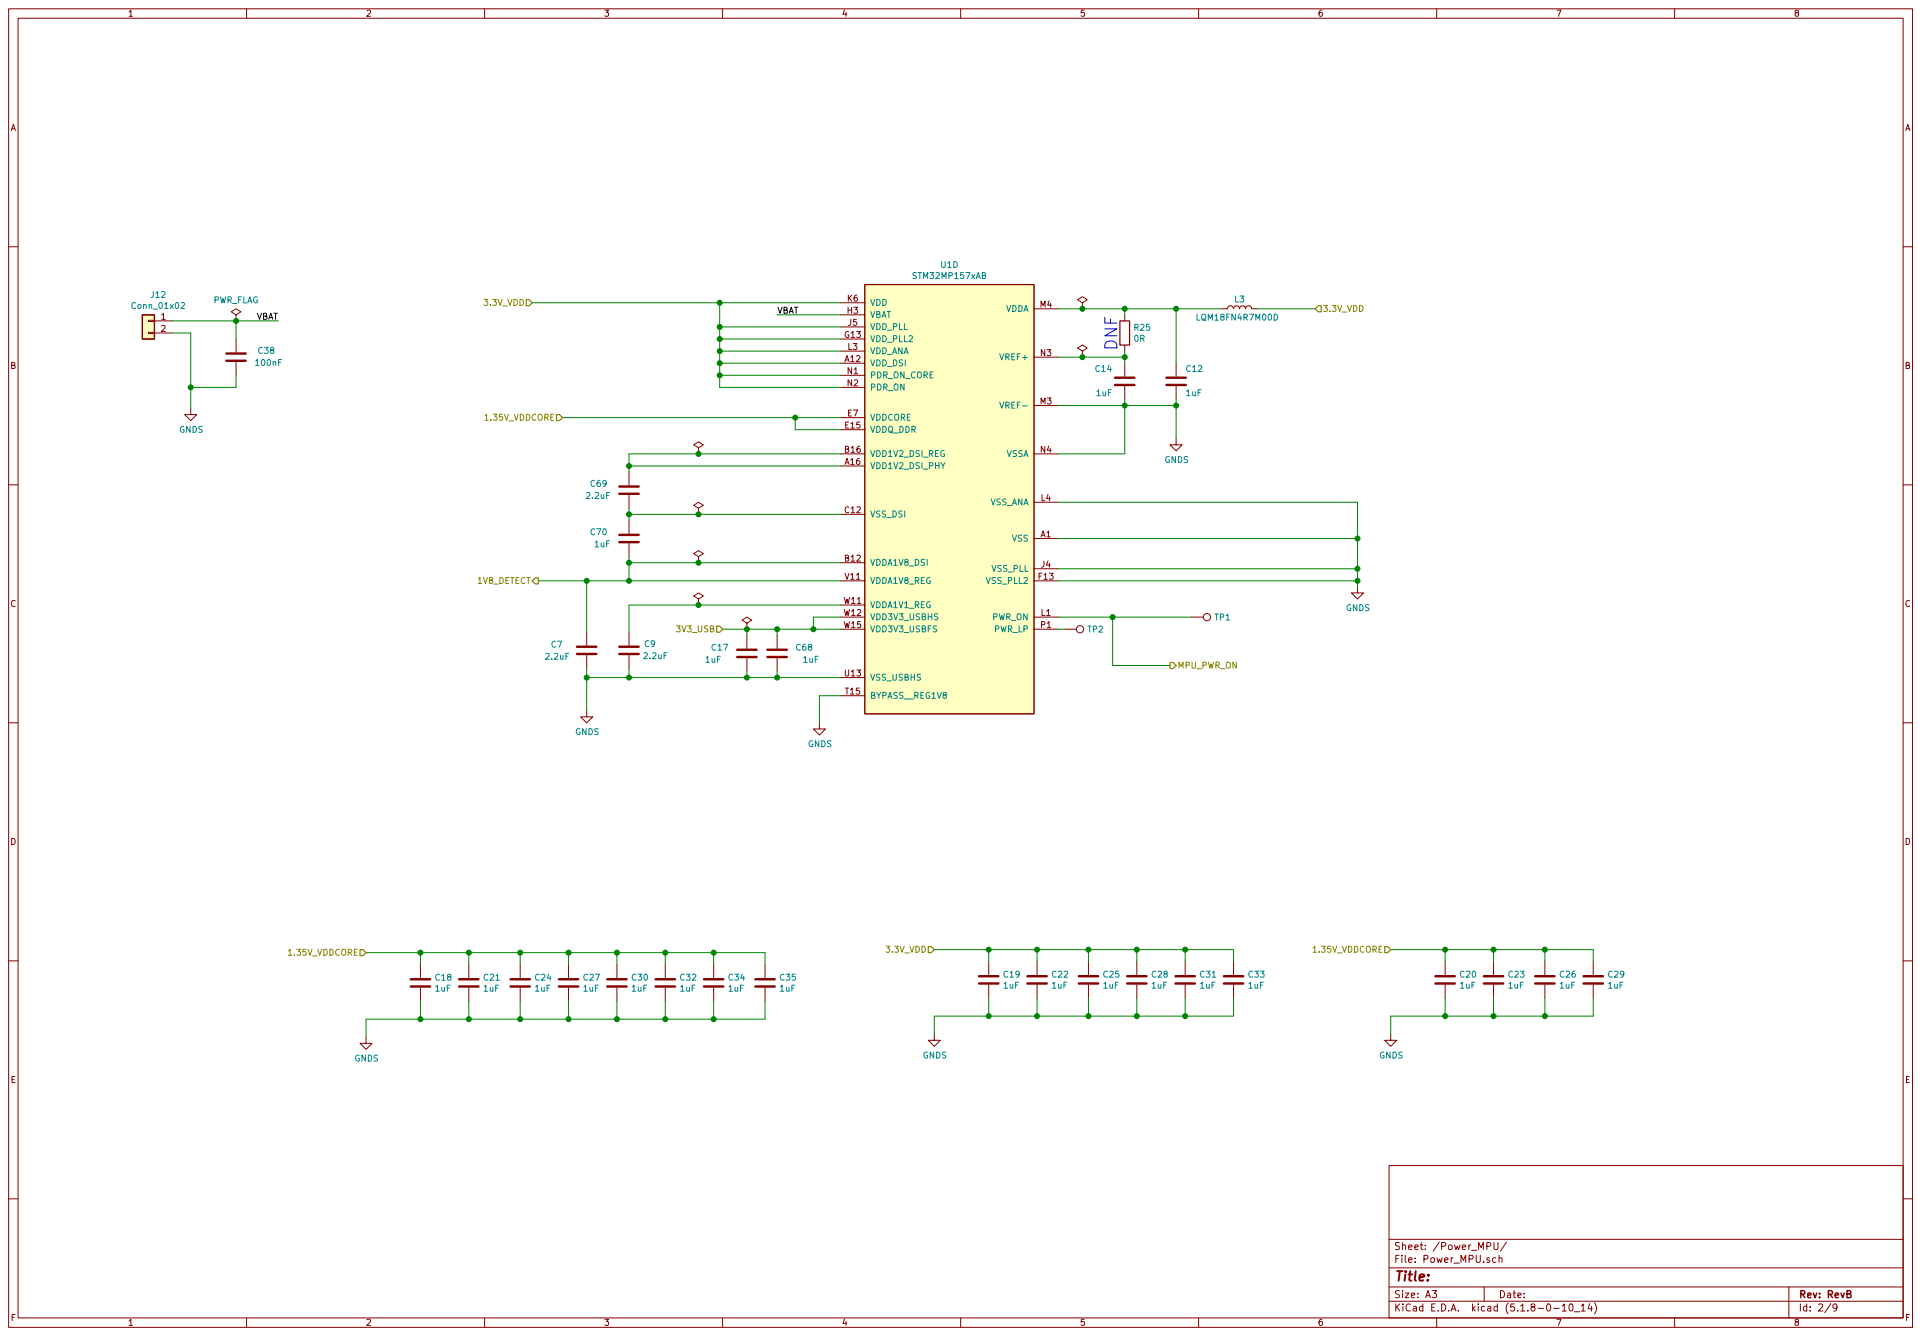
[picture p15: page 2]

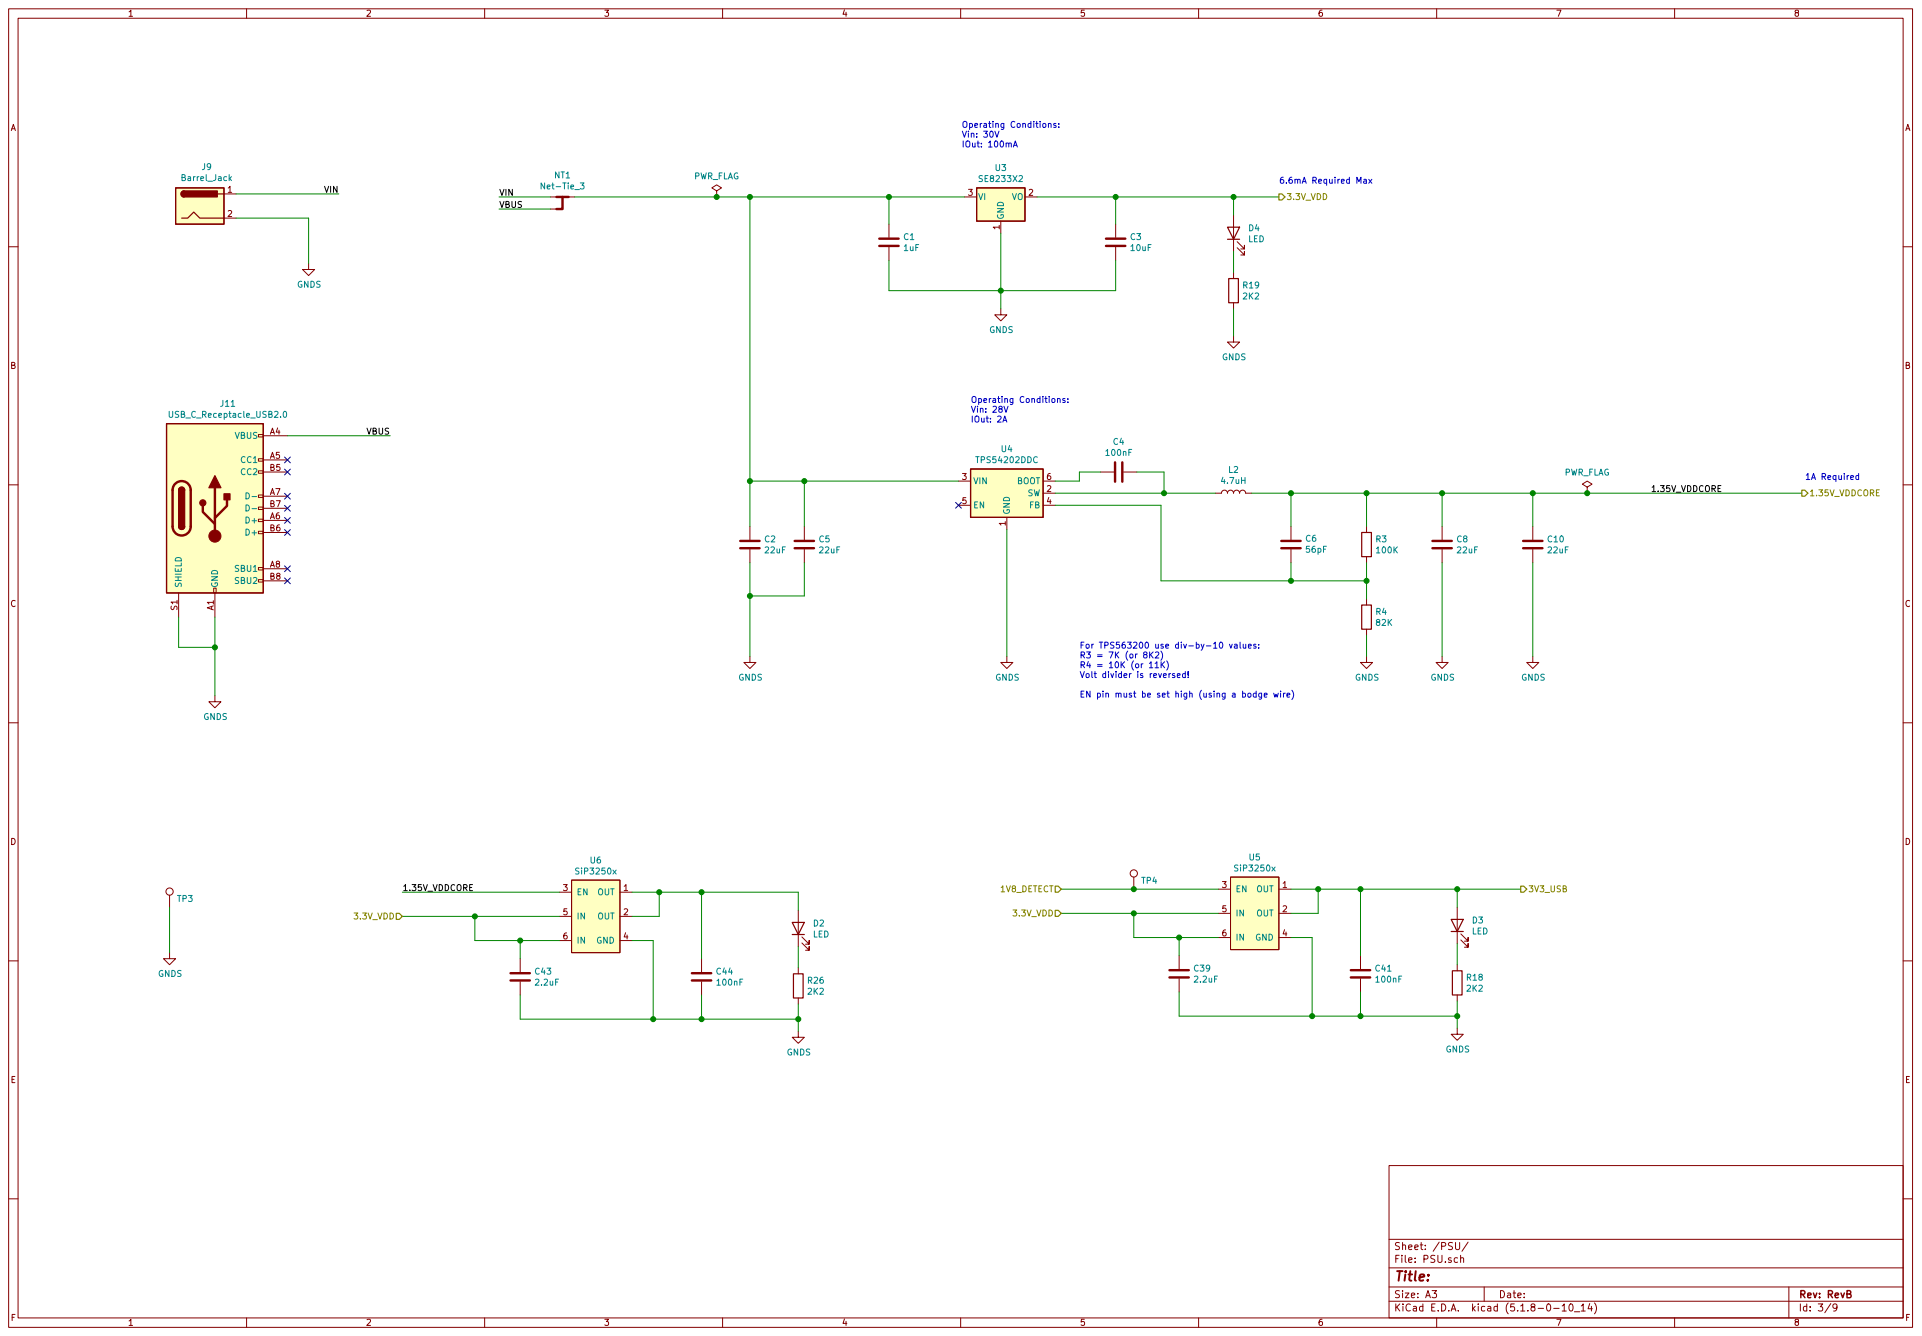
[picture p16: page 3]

1 SW 2 VIN 3 FB 4 EN 5 BOOT 6 U4 TPS54202DDC

Id: 3/9 Title: File: PSU.sch Sheet: /PSU/ GND

For TPS563200 use div-by-10 values:
R4 = 10K (or 11K) Volt divider is reversed! EN pin must be set high (using a bodge wire)

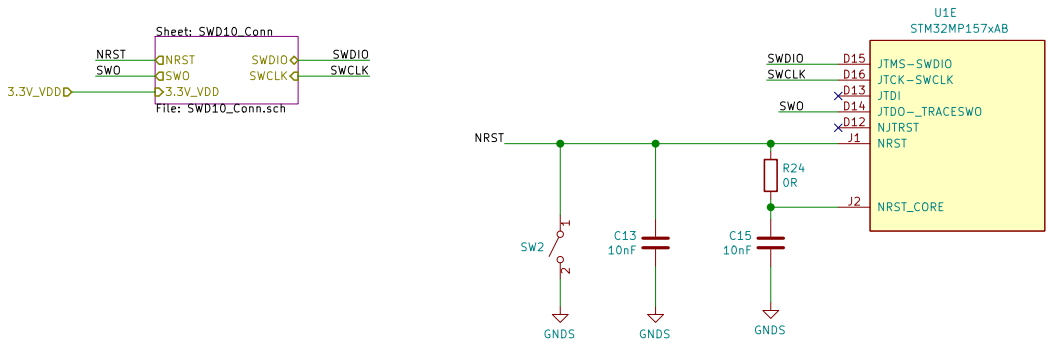
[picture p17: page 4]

Sheet: SWD10_Conn File: SWD10_Conn.sch SWCLK

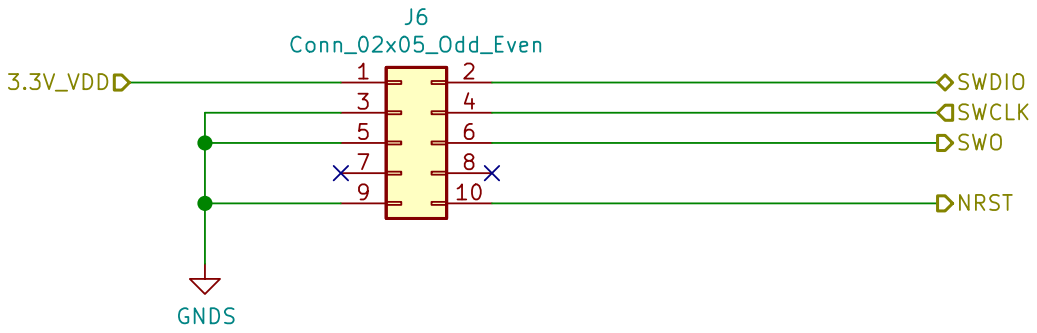
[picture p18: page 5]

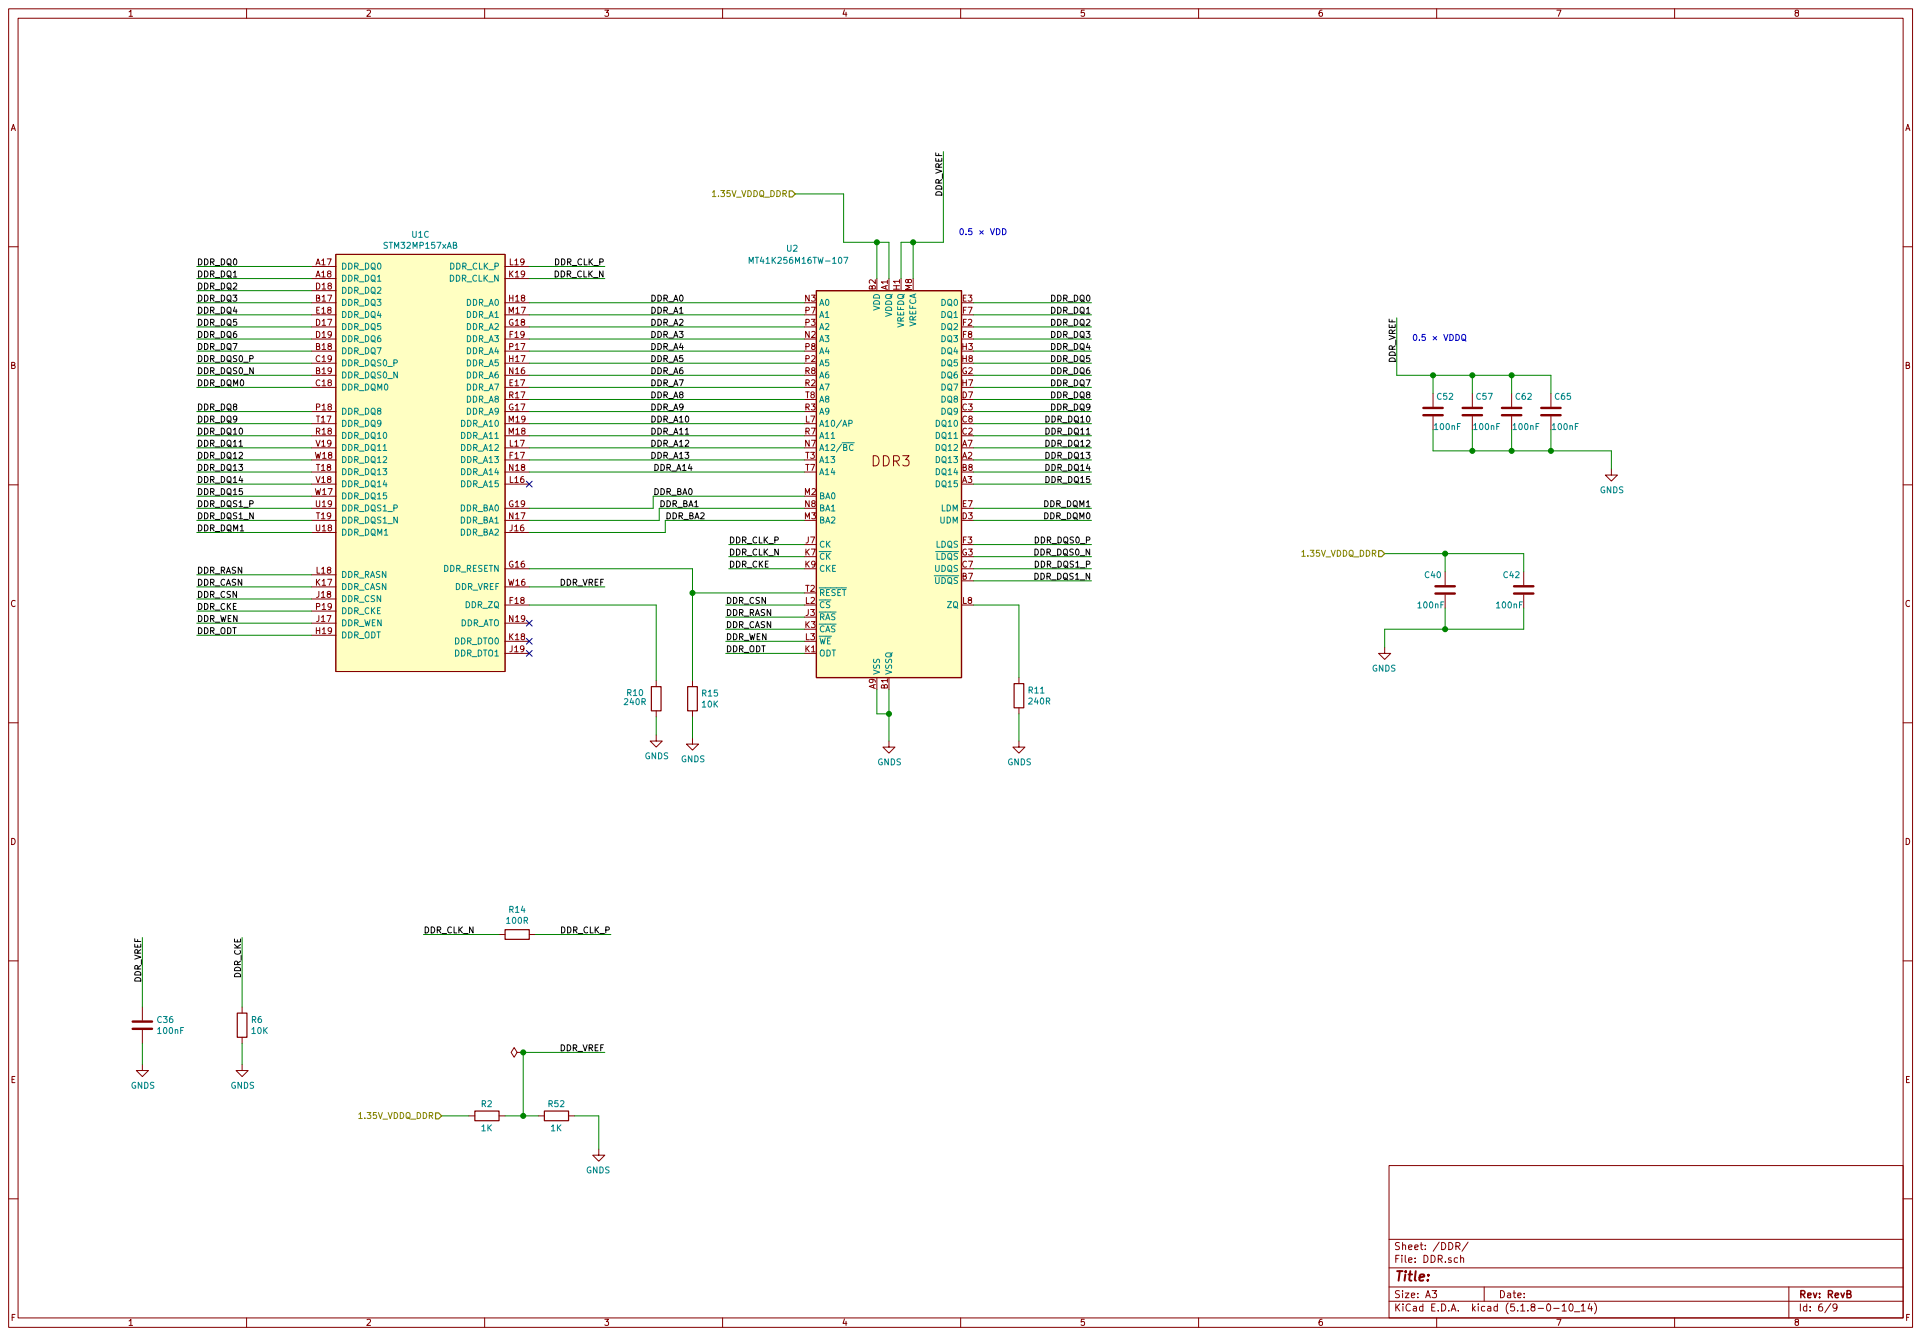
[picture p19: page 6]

Id: 6/9 Title: File: DDR.sch Sheet: /DDR/

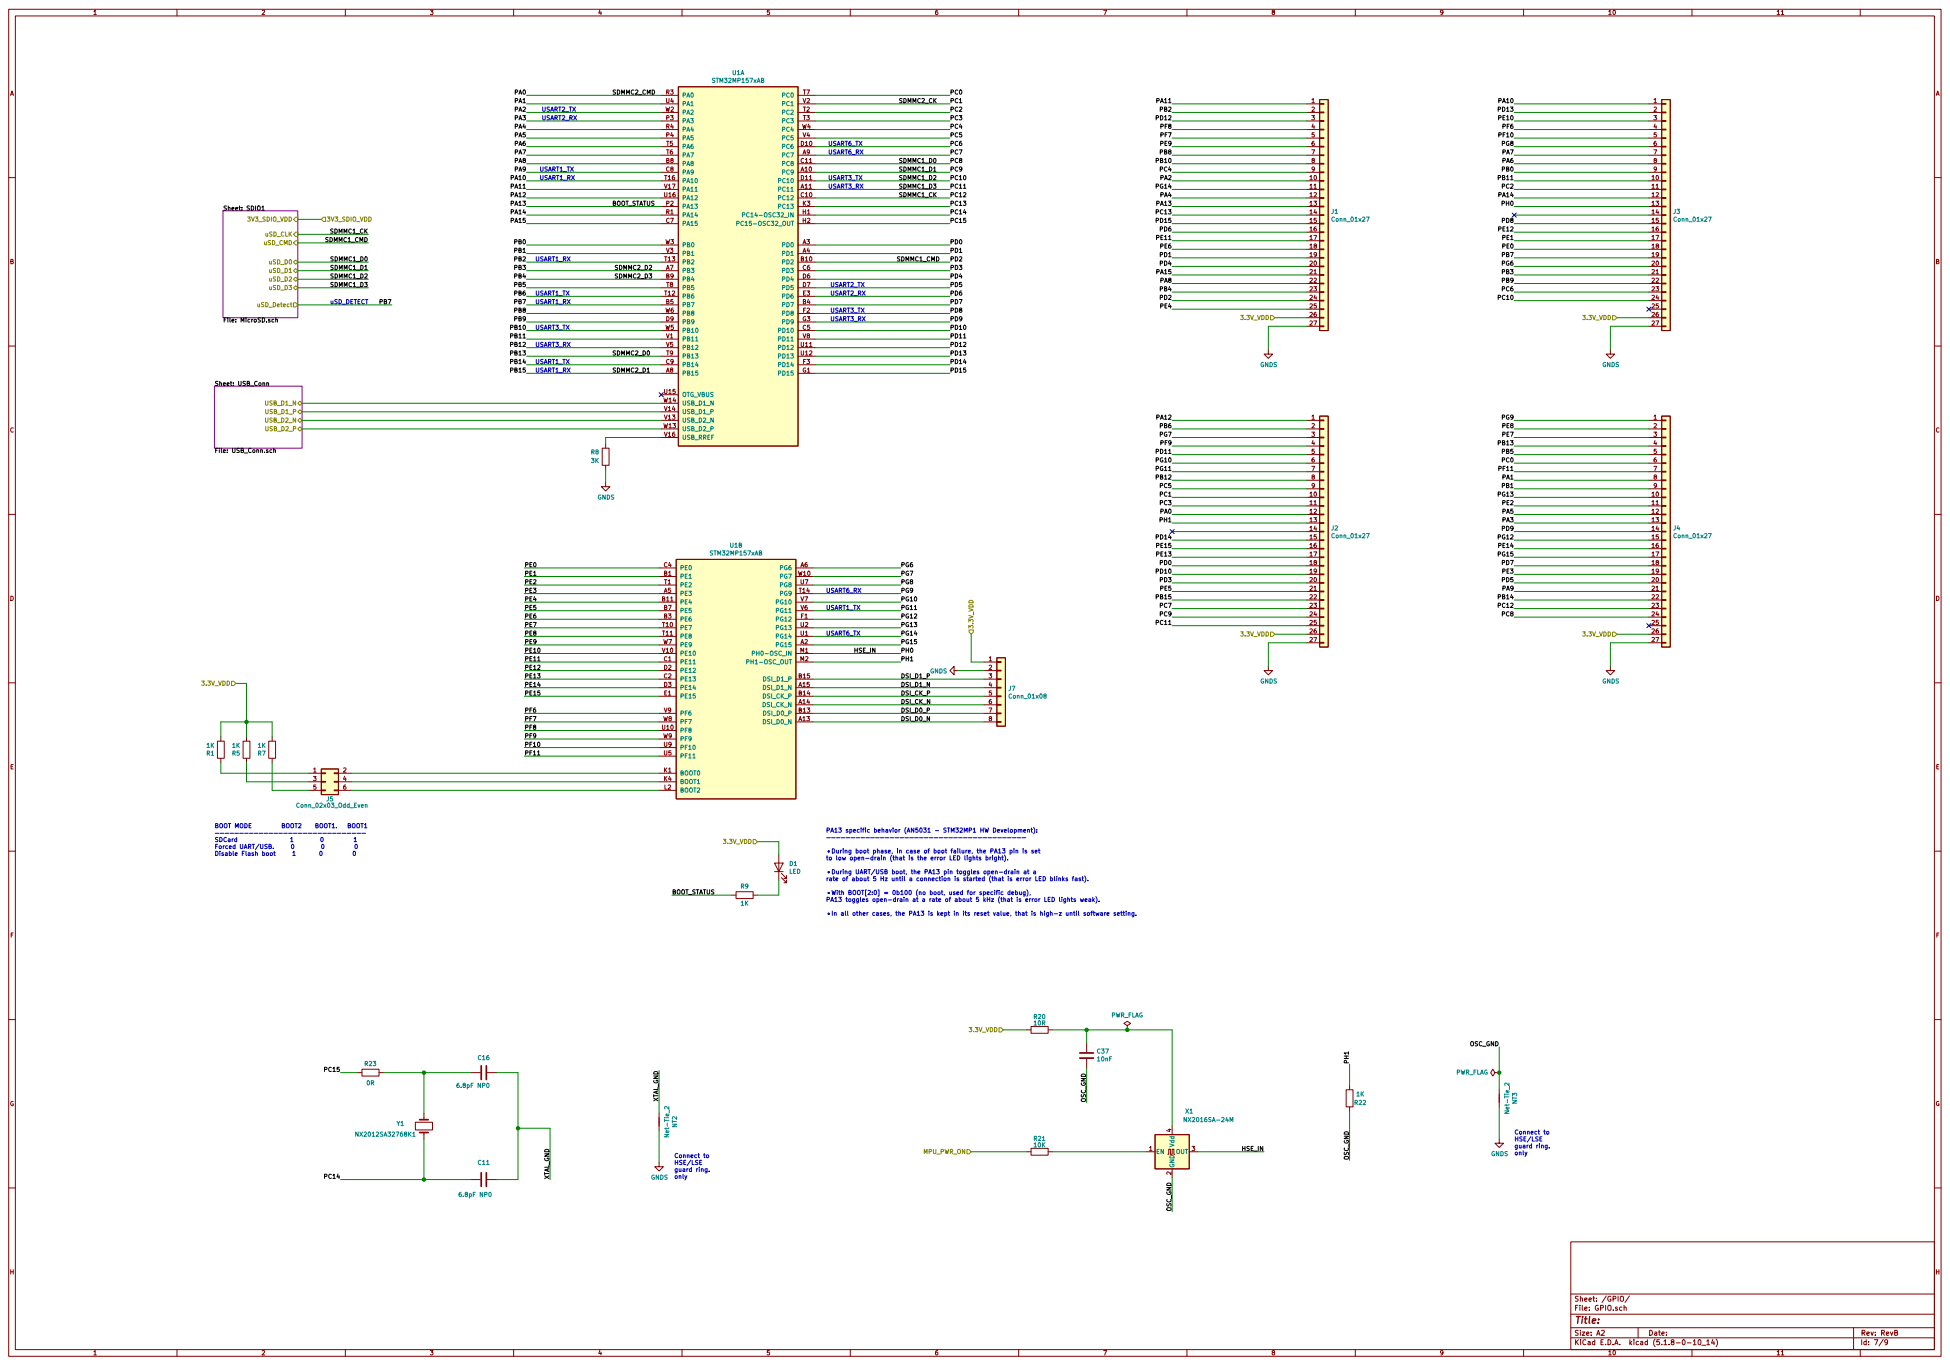
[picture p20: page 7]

Sheet: SDIO1 File: MicroSD.sch

PA13 specific behavior (AN5031 - STM32MP1 HW Development):

During boot phase, in case of boot failure, the PA13 pin is set
to low open-drain (that is the error LED lights bright).

During UART/USB boot, the PA13 pin toggles open-drain at a
rate of about 5 Hz until a connection is started (that is error LED blinks fast).

With BOOT[2:0] = 0b100 (no boot, used for specific debug),
PA13 toggles open-drain at a rate of about 5 kHz (that is error LED lights weak).

In all other cases, the PA13 is kept in its reset value, that is high-z until software setting.

Connect to HSE/LSE

Id: 7/9 Title: File: GPIO.sch Sheet: /GPIO/

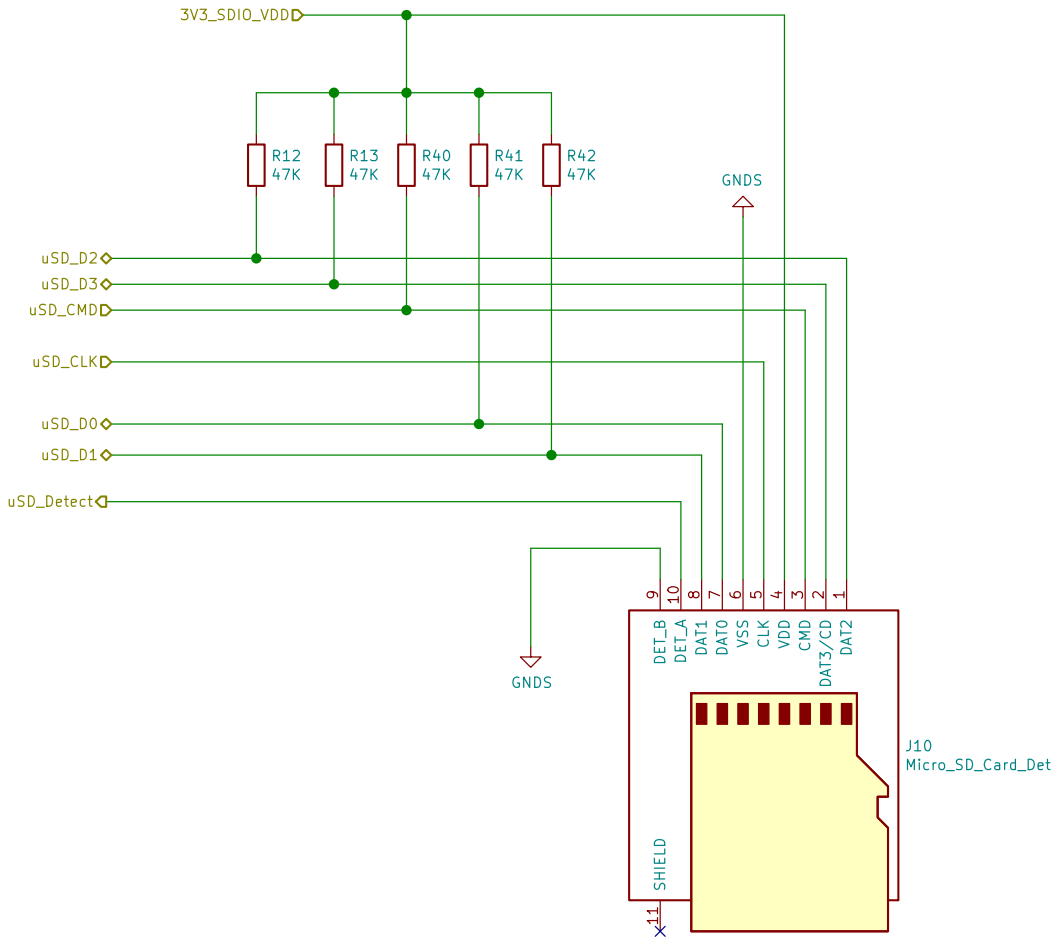
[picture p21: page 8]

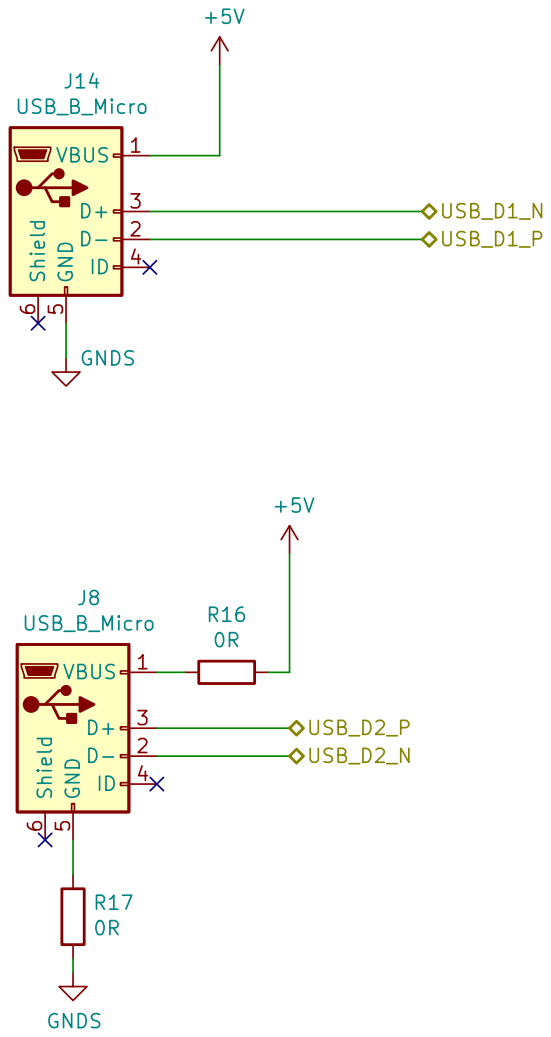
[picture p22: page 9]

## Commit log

2021-03-15 added project and updated readme
    [1050170001.stp, 475710001.stp, DC Power Jack 5.5mm x 2.1mm.STEP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]
2021-03-17 Removed 1.35V led and unused DDR capacitors
    [DDR.sch, PSU.sch]
2021-03-22 Updated design
    - Added Crystal/Oscillators
    - Replaced both SDMMC with single SDMMC w/ detect pin
    - Added USB Type C for VIN
    - Moved SWD pins
    - Tidied up silk screen for pin headers J1, J2, J3, J4
    - Moved DSI socket
    [1040310811.stp, 2137160001.stp, DDR.sch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]
2021-04-06 completed revb layout
    [DDR.sch, DebugInterface.sch, GPIO.sch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]
2021-04-08 updated revb
    - Fixed MIPI DSI differential trace spacings.
    - Moved passive components onto back of pcb
    [PSU.sch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]
2021-05-02 Tested RevB power supply
    Original BuckReg TPS54202
    Replacement BuckReg TPS563200
    [PSU.sch]
2021-06-18 fixed BOM error
    R4 listed with capacitor part number, corrected to resistor part number
    [GPIO.sch, PSU.sch, STM32MP1_TestBoard_RevB_JLCPCB.csv]
